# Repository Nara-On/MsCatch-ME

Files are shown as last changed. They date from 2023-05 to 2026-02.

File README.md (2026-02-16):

[][contributors-url]




<br />
<br />
<div align="center">
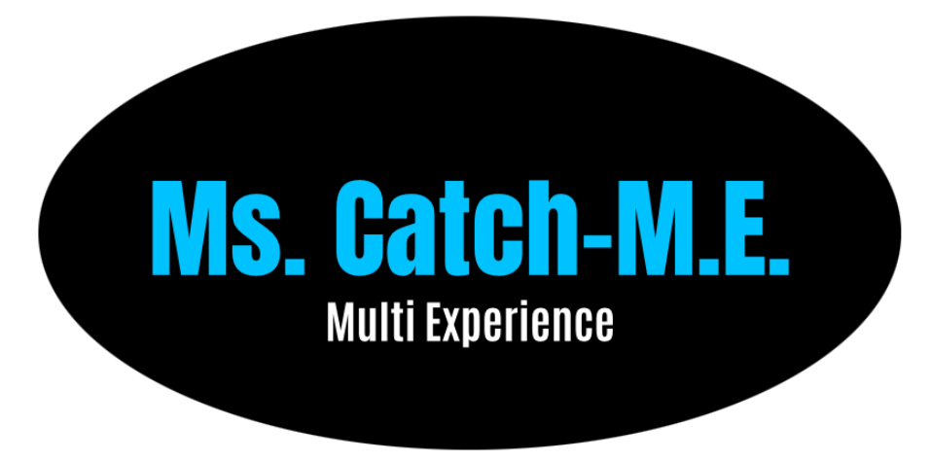
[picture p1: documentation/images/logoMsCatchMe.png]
  
  <h3 align="center">Ms. Catch-M.E.</h3>
  <p align="center">
    Arduino automated robot than plays games with you
    <br />
    https://youtu.be/ik0ufMCvqKk
    <br />
    <br />
</div>

<details>
  <summary>Table of Contents</summary>
  <br/>
    <li>
      <a href="#authors">Authors</a>
    </li>
    <li>
      <a href="#about-the-project">About The Project</a>
    </li>
    <li>
      <a href="#version-history">Version History</a>
    </li>
</details>

## Authors
Adrian Vargas Orellana - <a href="https://github.com/adriend1102">adriend1102</a> <br />
Marina Bermúdez Granados - <a href="https://github.com/nara-on">nara-on</a> <br />
Laia Rubio Castro - <a href="https://github.com/laiarubiio">laiarubiio</a> <br />
Erik Becerra Moreno - <a href="https://github.com/ERlK2021">ERlK2021</a><br />
Erik Villarreal Gallardo - <a href="https://github.com/LynxEko">LynxEko</a> 

<br >

## About the Project
<div align="center">
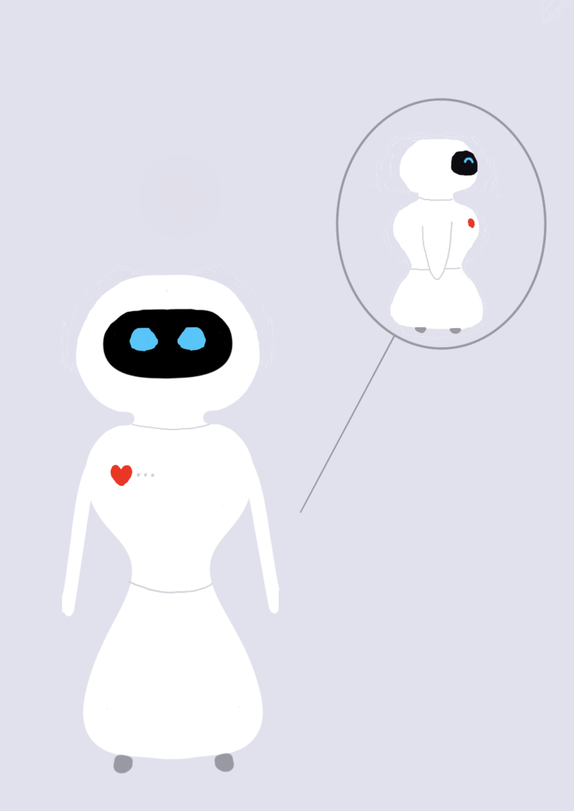
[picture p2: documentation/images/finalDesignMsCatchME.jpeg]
  
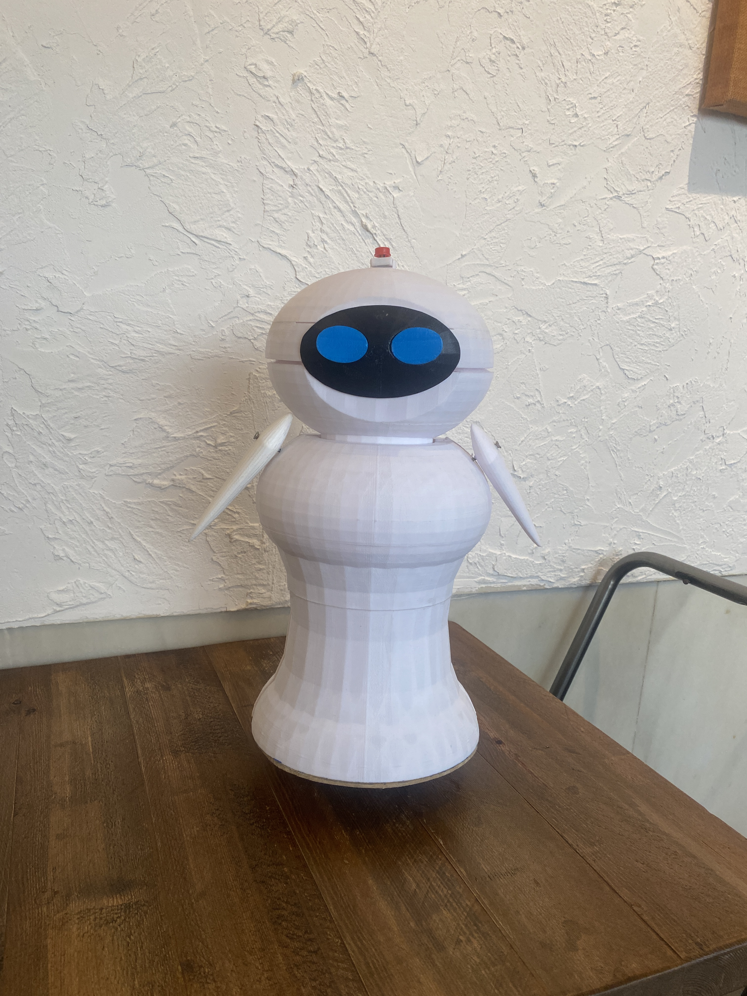
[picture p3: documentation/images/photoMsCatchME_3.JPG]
  
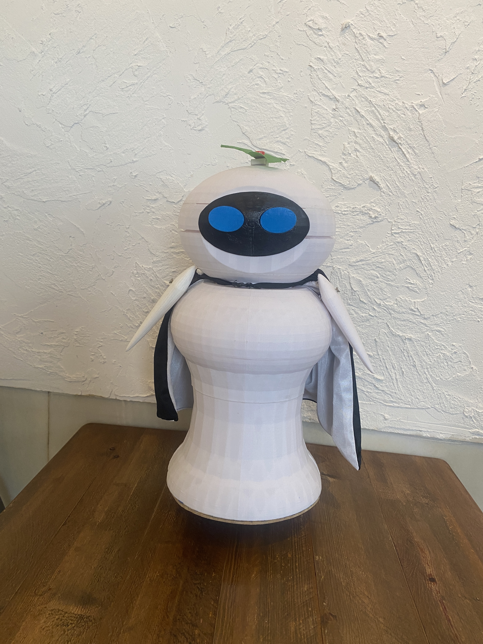
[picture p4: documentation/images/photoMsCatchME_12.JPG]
  
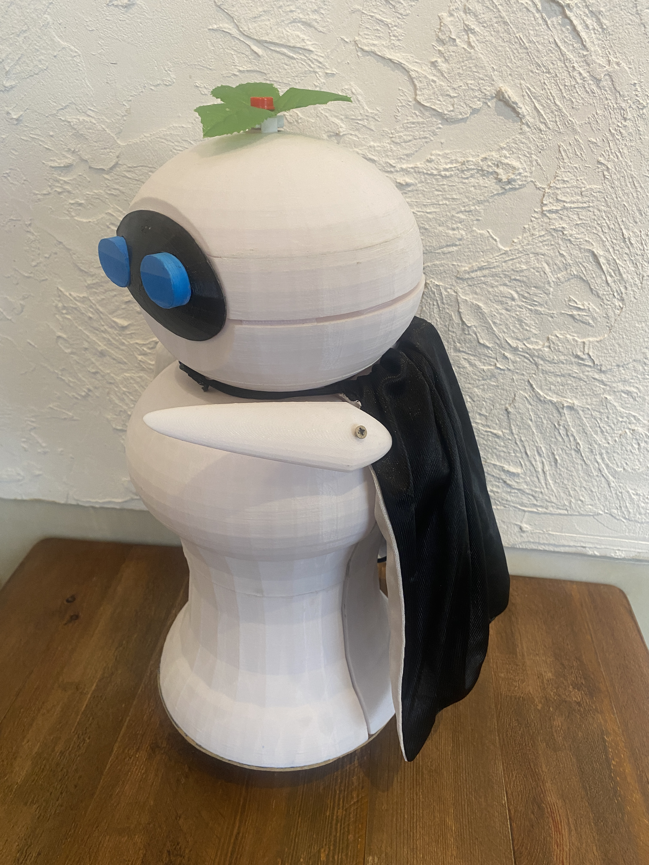
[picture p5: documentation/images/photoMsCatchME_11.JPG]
  
</div>

<br />

Ms. Catch Multi Experience (M.E.) is a Robot that can play games with children, like tag, hide and seek and red light - green light. The selection of the games will be done with a button when the robot says a specific game. In this repository stores the documentation, code and 3D models related to its development.

<br />

## Version History

* 3.0
    * <i>modulePicaPared.py</i> updated
    * <i>master.py</i> updated
    * Final report added
    * Presentation added
    * New audios added

<br />

* 2.1
    * Photos added
    * Schematics updated
* 2.0
    * <i>communication.py</i> added
    * <i>initButton.py</i> added
    * <i>catch_communication.h</i> added
    * <i>motor_control_serial.ino</i> added
    * <i>modulePicaPared.py</i> updated

<br />

* 1.1
    * <i>initAudio.py</i> added
    * <i>modulePicaPared.py</i> updated
* 1.0
    * <i>initCam.py</i> added
    * <i>moduleDeteccion.py</i> added
    * <i>modulePicaPared.py</i> added
    * <i>master.py</i> added

<br />

* 0.2
    * Software Arquitecture Diagrams added
* 0.1
    * Initial Release

[contributors-shield]: https://img.shields.io/github/contributors/othneildrew/Best-README-Template.svg?style=for-the-badge
[contributors-url]: https://github.com/Nara-On/MsCatch-ME/graphs/contributors

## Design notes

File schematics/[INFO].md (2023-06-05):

All models except the Raspberry CAM Holder and the Motor Brackets are made by ourselves.

Sources:

- Raspberry CAM Holder: https://www.thingiverse.com/thing:2987719
- Motor Brackets: https://grabcad.com/library/pololu-micro-motor-bracket-1

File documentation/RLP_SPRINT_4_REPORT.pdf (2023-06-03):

RPL - Computer Engineering. UAB (Barcelona) 2022-2023

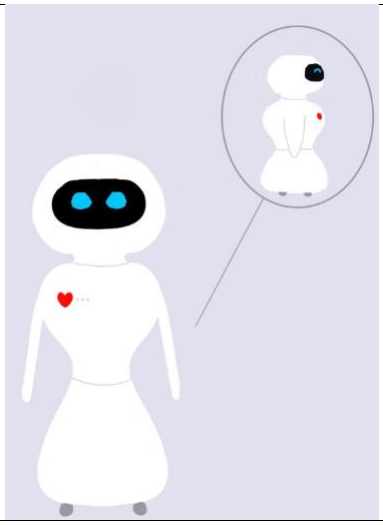
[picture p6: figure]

Ms. Catch-M.E.

Arduino automated robot than plays games with you

PROJECT SPRINT #4.
DATE: 3 Mayo 2023

Ms. Catch-M.E

Adrian Vargas Orellana

Marina Bermúdez Granados

Laia Rubio Castro

Erik Becerra Moreno

Erik Villarreal Gallardo

Ms. Catch-M.E

# Table of Contents

Strategy for validation, testing and simulation (COMPULSORY, only the strategy, you do

Sprint #2
Date: 15 April 2023
Ms. Catch-M.E | 1

Ms. Catch-M.E.

Robot que es capaç de jugar a un seguir de jocs infantils amb la finalitat d’entretenir la canalla.

Project description

Creació d’un robot que juga amb nens. Es capaç de jugar un seguir de jocs infantils amb la finalitat d’entretenir la canalla.

L’elecció del joc es farà mitjançant el boto que té. El procés consistirà en que cada vegada que el robot s’encengui enumerarà per veu cada joc, deixant un petit temps de resposta entre joc i joc. Serà en aquest temps quan el jugador haurà de prémer el boto en cas de voler aquesta modalitat. Un cop seleccionat el joc dirà: ‘Heu seleccionat x joc, voleu començar?’ En cas afirmatiu el jugador haurrà de prémer el botó i s’iniciarà el joc en els 20 segons posteriors (fent el compte enrere en els últims 10 segons per indicar-ho als jugadors). En cas negatiu, i per tant, que no es premi el botó, el robot tornarà a repetir les diferents modalitats.

Els jocs disponibles són:

‘Pilla-pilla’ :

- Funcionament: el jugador ha d’intentar esquivar el robot per a que no l’enganxi, ja que aquest l’anirà perseguint amb l’objectiu d’atrapar-lo.
- Fi: el robot contarà que ha atrapat el jugador quan detecti que la persona esta a 1 metre de distancia. En aquest moment emetrà una gravació dient: ‘Pillat’.

“Pilla-pilla invers”:

- Funcionament: el robot ha d’intentar esquivar el jugador per a que no l’enganxi, ja que aquest l’anirà perseguint amb l’objectiu d’atrapar-lo.
- Fi: el robot contarà que ha sigut atrapat quan el jugador premi el botó que te incorporat.

“Escondite”:

- Funcionament: el robot s’amaga i el jugador l’ha de trobar

Ms. Catch-M.E | 2
- Fi: quan el juagor trobi el robot haurà de polsar un botó que aquest t’he incorporat. En aquest moment el robot detectarà que ha sigut trobat i perdrà el joc.
- Com a ajuda, si el robot no ha sigut trobat en 5 min aquest emetrà un soroll per a facilitar el joc. Aquest procés es repetirà cada 5 min, si en 15 min aquest no ha sigut trobat guanyarà.

“Escondite invers”:

- Funcionament: el juagor s’amaga i el robot l’ha de trobar
- Fi: el robot anirà desplaçant-se per l’habitació i quan detecti una persona emetrà: ‘Pillat’. En cas d’haver transcorregut 15 min i no haver trobat al jugador, aquest perdrà.

“Pica-paret”:

- Funcionament: el robot es posarà de cara a la paret i emetrà una gravació de: ‘1, 2, 3 pica paret’ i es girarà per comprovar si el jugador s’ha mogut.
- Fi: quan el robot no estigui de cara a la paret, si aquest detecta que el jugador s’ha mogut emetrà una gravació dient: ‘pillat’ i aquest quedarà eliminat. El joc acabarà quan el jugador arribi a la posició del robot i premi el boto que porta incorporat o be quan el robot hagi eliminat al jugador.

Per a poder jugar a qualsevol dels jocs es necessari disposar d’un espai mes o menys ampli, amb terra pla sense imperfeccions marcades ni objectes petits sobre el sol.

Aquest robot esta pensat per a jugar amb un únic jugador per aquest motiu la dinàmica de tots els jocs seguirà la metodologia de: 1 vs 1.

Cada vegada que una partida acabi el robot emetrà una gravació que indicarà com a acabat el joc. En cas d’haver perdut emetrà música de derrota i en cas contrari música de victòria.

Segueix un disseny pensat per a infants, es a dir, d’una banda es resistent així com equilibrat per tal de poder suportar qualsevol possible col·lisió o cop per part dels jugadors. Ja que moltes vegades els nens no controlen la seva força, especialment a l’hora de jugar.

D’altra banda, es segur per als nens, no té cap cantonada o part punxant per evitar cap possible lesió durant els jocs.

Ms. Catch-M.E | 3

I finalment, en quan a la part estètica, al estar pensat per a un públic infantil, aquest segueix un disseny amigable i gens intimidant. A més, la incorporació de LEDs que reprodueixen expressions o canvis facials dependent de la situació facilita la relació nen-robot així com, fomenta la diversió. Donant un toc més humà al robot, semblant, fins a un cert punt, que s’està jugant amb una altre persona.

Electronic components

This is the list of the proposed components:

■ Adafruit Motor Shield per Arduino v2.3

■ Motor amb eix angle recte i reductora 48:1 [2]

■ Altaveu amb caixa - 3W

■ Sensor de distància per ultaso HC-SR04 [2]

■ Pulsador arcade amb interruptor (vermell)

■ Rasberry pi 3 model B+

■ AVR arduino uno rev 3

■ Bateria recarregable 8.4 V [2]

■ Arducam 5MP 1080p OV5647 RASBERRY PI

■ Adaptador 9V a jack alimentació 5.5x2.1mm positu inferior [2]

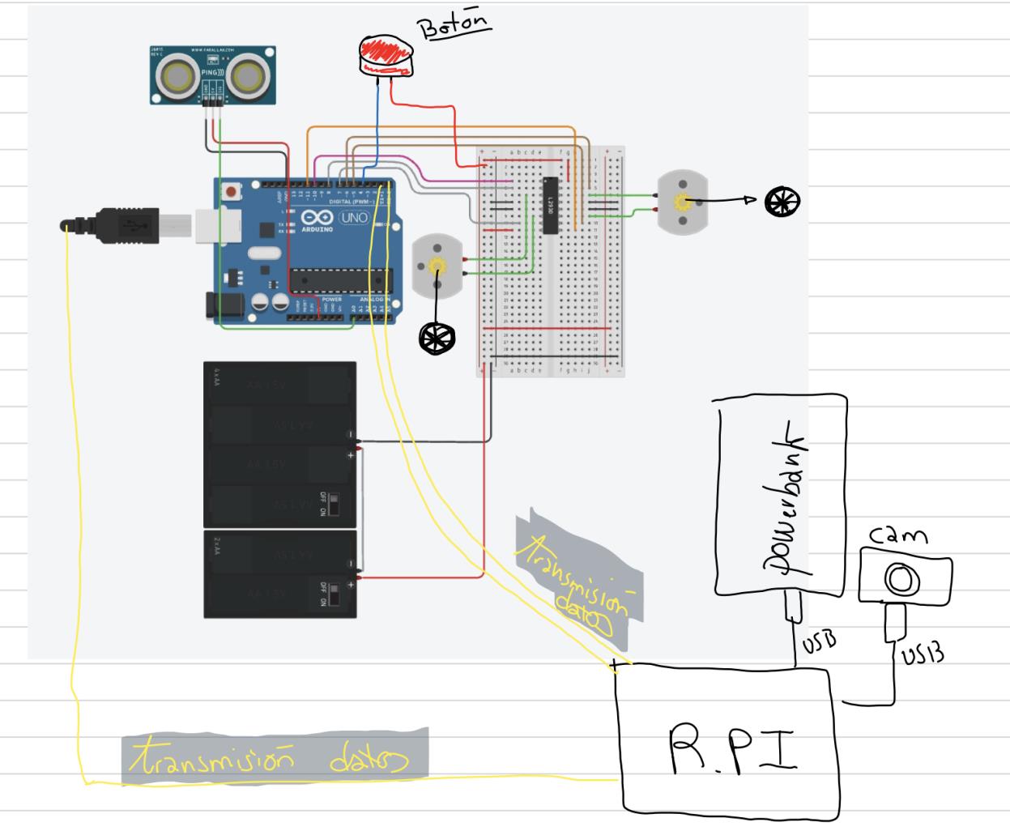
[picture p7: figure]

Ms. Catch-M.E | 4

Hardware Scheme (optional, in case that you already had this ready)

Software Architecture (COMPULSORY)

Es tractara de dos mòduls principals, el de visió controlat per una raspberry pi i el de control controlat per un arduino uno.

El mòdul d'arduino el programarem a través de C++ que anirá rebent les entrades de la raspberry i també generarà sortides cap a la raspberry. Aquestes sortides serán per exemple el sensor d'ultrasons o el botó que el nostre robot tindrá.

Ms. Catch-M.E | 5

La raspberry Pi (encara estem debatent com implementar-ho si en python o c++) però l'idea seria fer-ho conectada per wifi a una API de google. L'idea seria que enregistri el joc que volem seleccionar, quan ha començat o finalitzat el joc, també les dades de la càmera i generarà com a sortides per exemple la velocitat dels motors, a quina direcció ha de girar el robot, si hi ha moviment pel joc del pica pared...

Tot i això la arquitectura encara l'hem de aprofundir i el descrit anteriorment es una proposta provisional.

Ms. Catch-M.E | 6

Amazing contributions (COMPULSORY)

- Aquest robot podria suposar un avanç en el món de les joguines interactives, ja que moltes només tenen control de veu o tenen una funcionalitat molt simple. Entenem que tot això ha de ser pel preu, però si la nostra joguina un cop prototipada es construís en massa, els costos podrien baixar significativament.
- En el nostre robot no ho tenim pensat implementar (que es podria), però es pot extrapolar les funcionalitats del robot en un altre àmbit com per exemple el de seguretat. Per exemple, faci vigilància en una casa o un apartament i si entra algun lladre que envií una alerta a la policia.
- També s’hauria de tenir en compte que no hi ha molts robots semblants en el mercat amb tantes funcions que tinguin una intel·ligència artificial molt elevada de manera que es tracta d’un projecte complex que no s’ha comercialitzat en gran escala.

Aquest projecte està dissenyat per arribar a un 10 en el cas que es compleixi tots els objectius principals. Durant el seu desenvolupament, amb aquest robot es treballarà la part Hardware i la part Software incloent Visió per Computador. En aconseguir-ho, al final es tindrà un robot funcional capaç d’interactuar amb els participants en diversos jocs a través d’una càmara, una demo d’una joguina bastant complexa.

Extra components and 3D pieces

- Braç [1]
- Cap (base) [2]
- Cap (part superior) [3]
- Tronc inferior del cos [4]
- Tronc superior del cos [5]
- Ulls i cara [6]

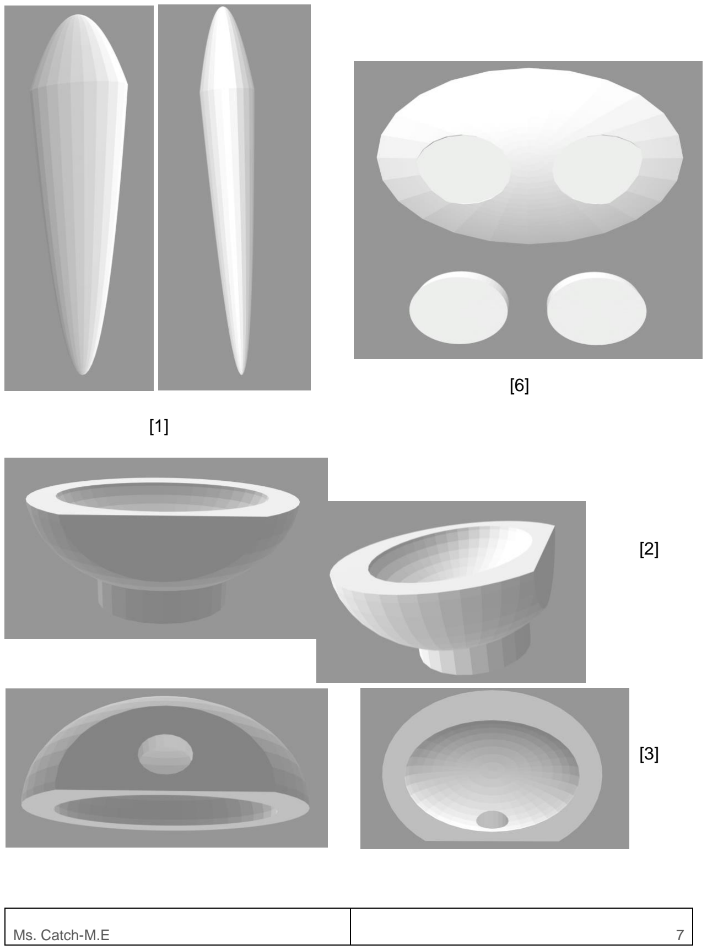
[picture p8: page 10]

Ms. Catch-M.E | 7

[6]

[1]

[2]

[3]

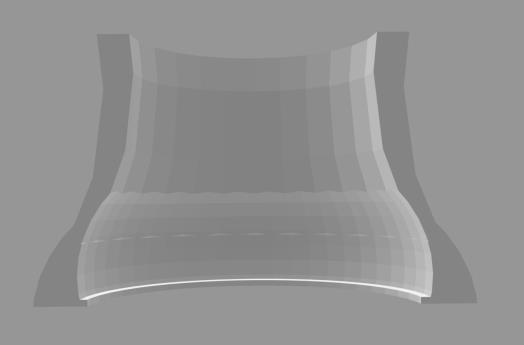
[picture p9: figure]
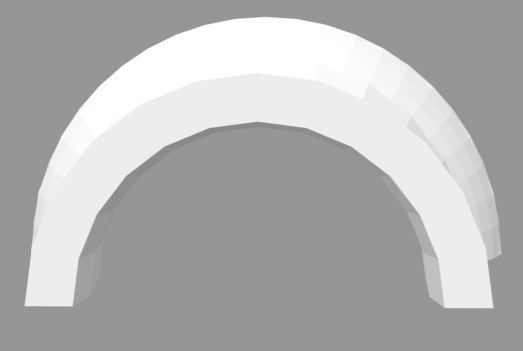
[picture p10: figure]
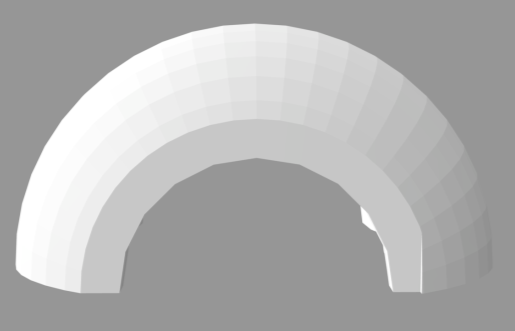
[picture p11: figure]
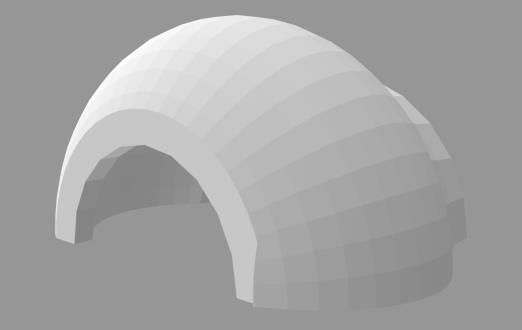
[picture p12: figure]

Ms. Catch-M.E | 8

[4]

[5]

Strategy for validation, testing and simulation (COMPULSORY, only the strategy, you do not need the tests to be done yet at this stage)

Principalment, hauríem de fer testing de cada component individualment i a més en conjunt (que accepti les entrades i generi les sortides esperades). D'aquesta manera, si hi ha alguna funció que no funciona i no trobem la raó, això ens pot ajudar.

La idea és separar totes les funcionalitats en mòduls diferents, de manera que els podem desglossar tant per fer la validació com per fer el test d'aquests.

Després anirem ajuntant els diferents mòduls i es realitzaran tests també per aquests (ex. detecció de persones i actuació del robot).

En el nostre cas intentarem seguir la metodologia de TDD (aprofitant que tenim un integrant de la menció d'ES) per tractar de fer la validació i el testing a la vegada.

Ms. Catch-M.E | 9

Foreseen risks and contingency plan

Aquestos són els riscos principals del nostre projecte. A mesura que anem fent el robot, sortiran més. Per això aquesta taula està subjecta a canvis.

Ris k # | Description | Probability (High/Medium/L ow) | Impact (High/Medium/ Low) | Contingency plan
R01 | Poca velocitat de motor | High | Medium | Intentar obtenir motors amb més potencia i/o velocitat (depen del problema) o utilitzar una serie de engranatges per adequar la força i la velocitat al nostre robot.
R02 | La recepció del wifi que rep la raspberry no és suficient | Medium | Medium | Tenir en compte alternatives de targetes de xarxa usb amb millor recepció.
R03 | Necessitat de components adicionals | Medium | High | Tractar d'extrapolar el funcionament del qual necessitem a un altre component si es pot i en cas contrari tractar d'obtenir-lo a un preu raonable.
R04 | Que una empresa diferent vulgui fer un robot similar | Low | High | Tractar d’innovar i oferir alguna cosa que aquesta empresa no pugui oferir amb el seu producte.
R05 | Que les impressions 3d no les tinguem a temps (ja sigui per la disponibilitat de les peces, que no hagin sortit bé..) | Low | High | Utilitzar una impressora 3d pròpia (Erik Becerra disposa d'una) o generar peces a partir de cartro

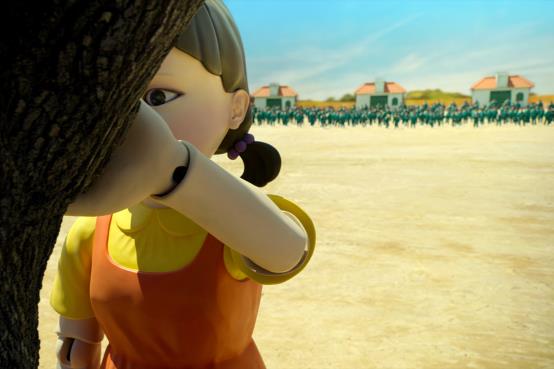
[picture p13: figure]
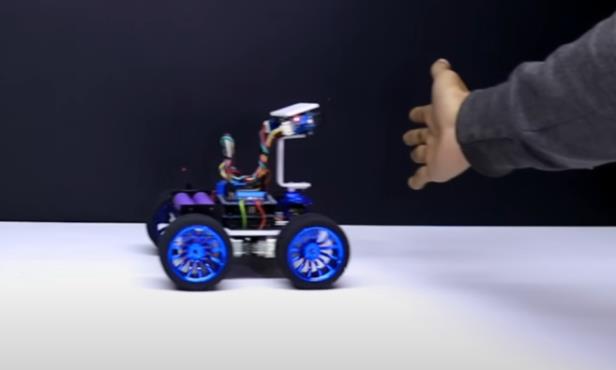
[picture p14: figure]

Ms. Catch-M.E | 10

# References

This project has been inspired by the following Internet projects:

https://www.youtube.com/watch?v=Ao7KbQLd2ms

https://www.youtube.com/watch?v=yAV5aZ0unag

https://www.thingiverse.com/thing:3703555

Statues/GLRL Game | Tag Game

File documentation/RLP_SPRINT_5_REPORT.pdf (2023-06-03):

RPL - Computer Engineering. UAB (Barcelona) 2022-2023


Ms. Catch-M.E.

Arduino automated robot than plays games with you

PROJECT SPRINT #4.
DATE: 3 Mayo 2023

Ms. Catch-M.E

Adrian Vargas Orellana

Marina Bermúdez Granados

Laia Rubio Castro

Erik Becerra Moreno

Erik Villarreal Gallardo

Ms. Catch-M.E

# Table of Contents

Project description | 1
Electronic components | 3
Hardware Scheme (optional, in case that you already had this ready) | 3
Software Architecture (COMPULSORY) | 4
Amazing contributions (COMPULSORY) | 5
Extra components and 3D pieces | 5
[4] 7
Strategy for validation, testing and simulation (COMPULSORY, only the strategy, you do
not need the tests to be done yet at this stage) | 7
Foreseen risks and contingency plan | 8

Sprint #5
Date: 5 june 2023
Ms. Catch-M.E | 1

Ms. Catch-M.E.

Robot que es capaç de jugar a un seguir de jocs infantils amb la finalitat d’entretenir la canalla.

Project description

Creació d’un robot que juga amb nens. Es capaç de jugar un seguir de jocs infantils amb la finalitat d’entretenir la canalla.

L’elecció del joc es farà mitjançant el boto que té. El procés consistirà en que cada vegada que el robot s’encengui enumerarà per veu cada joc, deixant un petit temps de resposta entre joc i joc. Serà en aquest temps quan el jugador haurà de prémer el boto en cas de voler aquesta modalitat. Un cop seleccionat el joc dirà: ‘Heu seleccionat x joc, voleu començar?’ En cas afirmatiu el jugador haurrà de prémer el botó i s’iniciarà el joc en els 20 segons posteriors (fent el compte enrere en els últims 10 segons per indicar-ho als jugadors). En cas negatiu, i per tant, que no es premi el botó, el robot tornarà a repetir les diferents modalitats.

Els jocs disponibles són:

‘Pilla-pilla’ :

- Funcionament: el jugador ha d’intentar esquivar el robot per a que no l’enganxi, ja que aquest l’anirà perseguint amb l’objectiu d’atrapar-lo.
- Fi: el robot contarà que ha atrapat el jugador quan detecti que la persona esta a 1 metre de distancia. En aquest moment emetrà una gravació dient: ‘Pillat’.

“Pilla-pilla invers”:

- Funcionament: el robot ha d’intentar esquivar el jugador per a que no l’enganxi, ja que aquest l’anirà perseguint amb l’objectiu d’atrapar-lo.
- Fi: el robot contarà que ha sigut atrapat quan el jugador premi el botó que te incorporat.

“Escondite”:

- Funcionament: el robot s’amaga i el jugador l’ha de trobar

Ms. Catch-M.E | 2
- Fi: quan el juagor trobi el robot haurà de polsar un botó que aquest t’he incorporat. En aquest moment el robot detectarà que ha sigut trobat i perdrà el joc.
- Com a ajuda, si el robot no ha sigut trobat en 5 min aquest emetrà un soroll per a facilitar el joc. Aquest procés es repetirà cada 5 min, si en 15 min aquest no ha sigut trobat guanyarà.

“Escondite invers”:

- Funcionament: el juagor s’amaga i el robot l’ha de trobar
- Fi: el robot anirà desplaçant-se per l’habitació i quan detecti una persona emetrà: ‘Pillat’. En cas d’haver transcorregut 15 min i no haver trobat al jugador, aquest perdrà.

“Pica-paret”:

- Funcionament: el robot es posarà de cara a la paret i emetrà una gravació de: ‘1, 2, 3 pica paret’ i es girarà per comprovar si el jugador s’ha mogut.
- Fi: quan el robot no estigui de cara a la paret, si aquest detecta que el jugador s’ha mogut emetrà una gravació dient: ‘pillat’ i aquest quedarà eliminat. El joc acabarà quan el jugador arribi a la posició del robot i premi el boto que porta incorporat o be quan el robot hagi eliminat al jugador.

Per a poder jugar a qualsevol dels jocs es necessari disposar d’un espai mes o menys ampli, amb terra pla sense imperfeccions marcades ni objectes petits sobre el sol.

Aquest robot esta pensat per a jugar amb un únic jugador per aquest motiu la dinàmica de tots els jocs seguirà la metodologia de: 1 vs 1.

Cada vegada que una partida acabi el robot emetrà una gravació que indicarà com a acabat el joc. En cas d’haver perdut emetrà música de derrota i en cas contrari música de victòria.

Segueix un disseny pensat per a infants, es a dir, d’una banda es resistent així com equilibrat per tal de poder suportar qualsevol possible col·lisió o cop per part dels jugadors. Ja que moltes vegades els nens no controlen la seva força, especialment a l’hora de jugar.

D’altra banda, es segur per als nens, no té cap cantonada o part punxant per evitar cap possible lesió durant els jocs.

Ms. Catch-M.E | 3

I finalment, en quan a la part estètica, al estar pensat per a un públic infantil, aquest segueix un disseny amigable i gens intimidant. A més, la incorporació de LEDs que reprodueixen expressions o canvis facials dependent de la situació facilita la relació nen-robot així com, fomenta la diversió. Donant un toc més humà al robot, semblant, fins a un cert punt, que s’està jugant amb una altre persona.

Electronic components

This is the list of the proposed components:

■ Adafruit Motor Shield per Arduino v2.3

■ Motor amb eix angle recte i reductora 48:1 [2]

■ Altaveu amb caixa - 3W

■ Sensor de distància per ultaso HC-SR04 [2]

■ Pulsador arcade amb interruptor (vermell)

■ Rasberry pi 3 model B+

■ AVR arduino uno rev 3

■ Bateria recarregable 8.4 V [2]

■ Arducam 5MP 1080p OV5647 RASBERRY PI

■ Adaptador 9V a jack alimentació 5.5x2.1mm positu inferior [2]


Ms. Catch-M.E | 4

Hardware Scheme (optional, in case that you already had this ready)

Software Architecture (COMPULSORY)

Es tractara de dos mòduls principals, el de visió controlat per una raspberry pi i el de control controlat per un arduino uno.

El mòdul d'arduino el programarem a través de C++ que anirá rebent les entrades de la raspberry i també generarà sortides cap a la raspberry. Aquestes sortides serán per exemple el sensor d'ultrasons o el botó que el nostre robot tindrá.

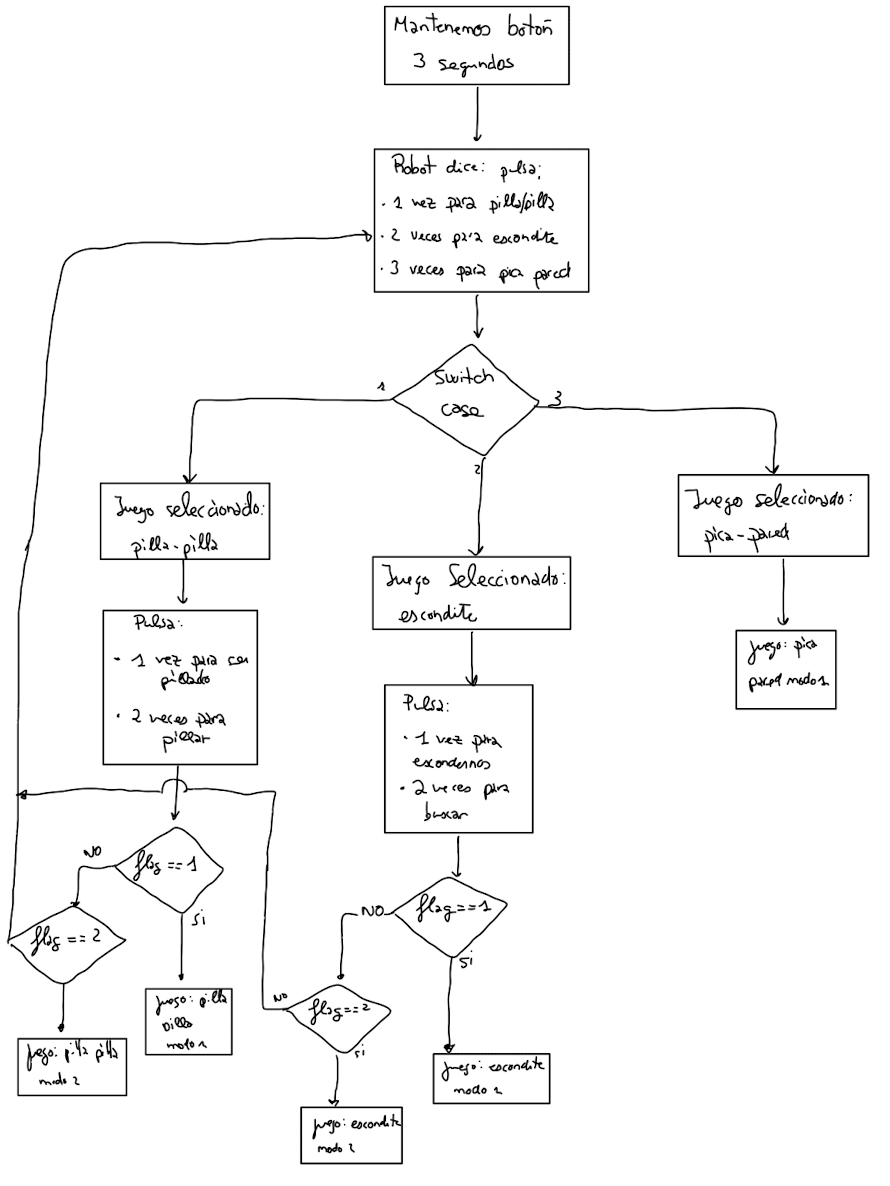
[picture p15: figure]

Ms. Catch-M.E | 5

La raspberry Pi (encara estem debatent com implementar-ho si en python o c++) però l'idea seria fer-ho conectada per wifi a una API de google. L'idea seria que enregistri el joc que volem seleccionar, quan ha començat o finalitzat el joc, també les dades de la càmera i generarà com a sortides per exemple la velocitat dels motors, a quina direcció ha de girar el robot, si hi ha moviment pel joc del pica pared...

Tot i això la arquitectura encara l'hem de aprofundir i el descrit anteriorment es una proposta provisional.

### Diagrames de fluxe

Selecció de fluxe

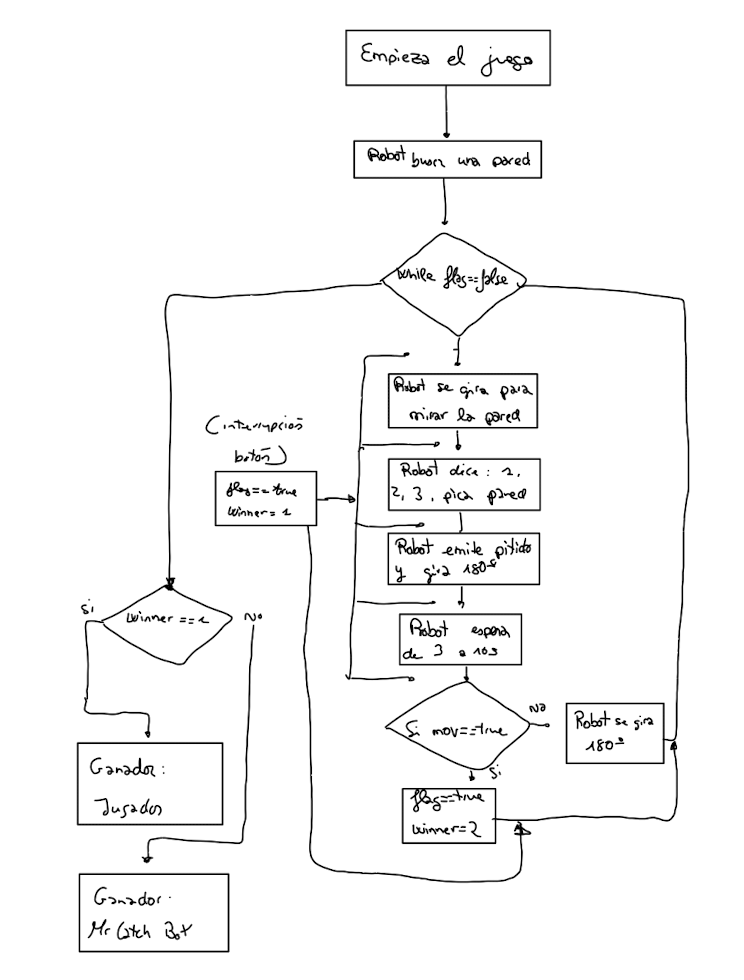
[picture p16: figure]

Ms. Catch-M.E | 6

Pica-paret

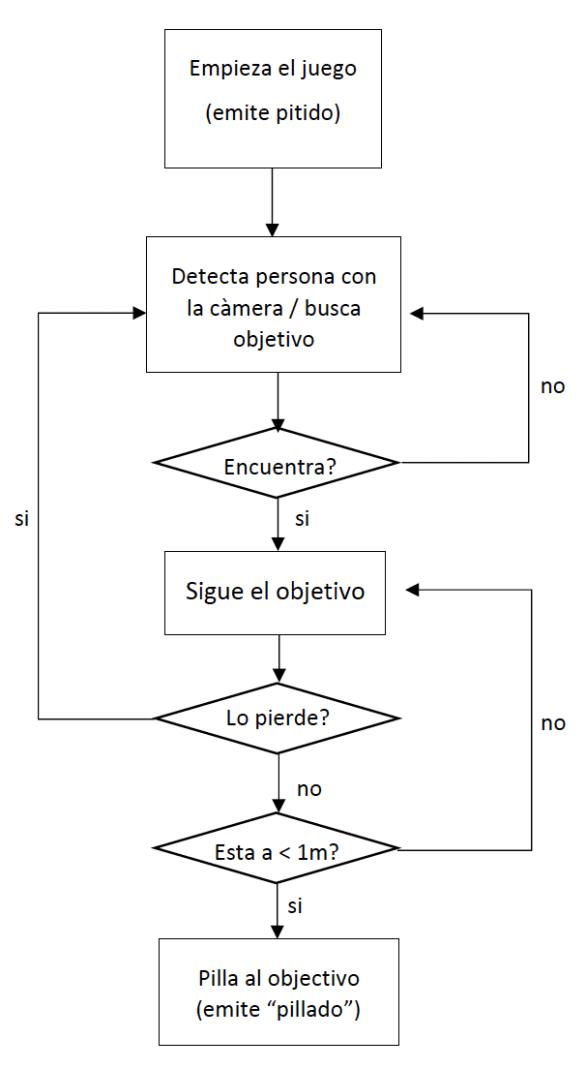
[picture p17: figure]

Ms. Catch-M.E | 7

Pilla-pilla:

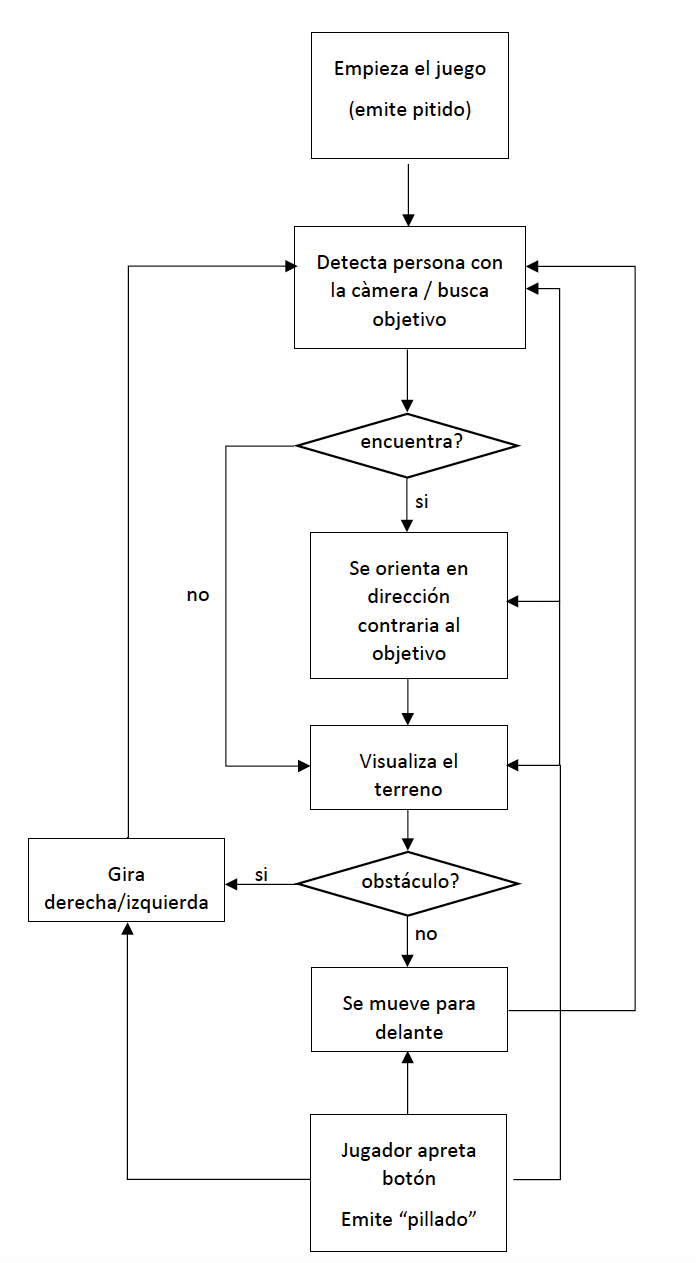
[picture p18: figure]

Ms. Catch-M.E | 8

Pilla-pilla invers:

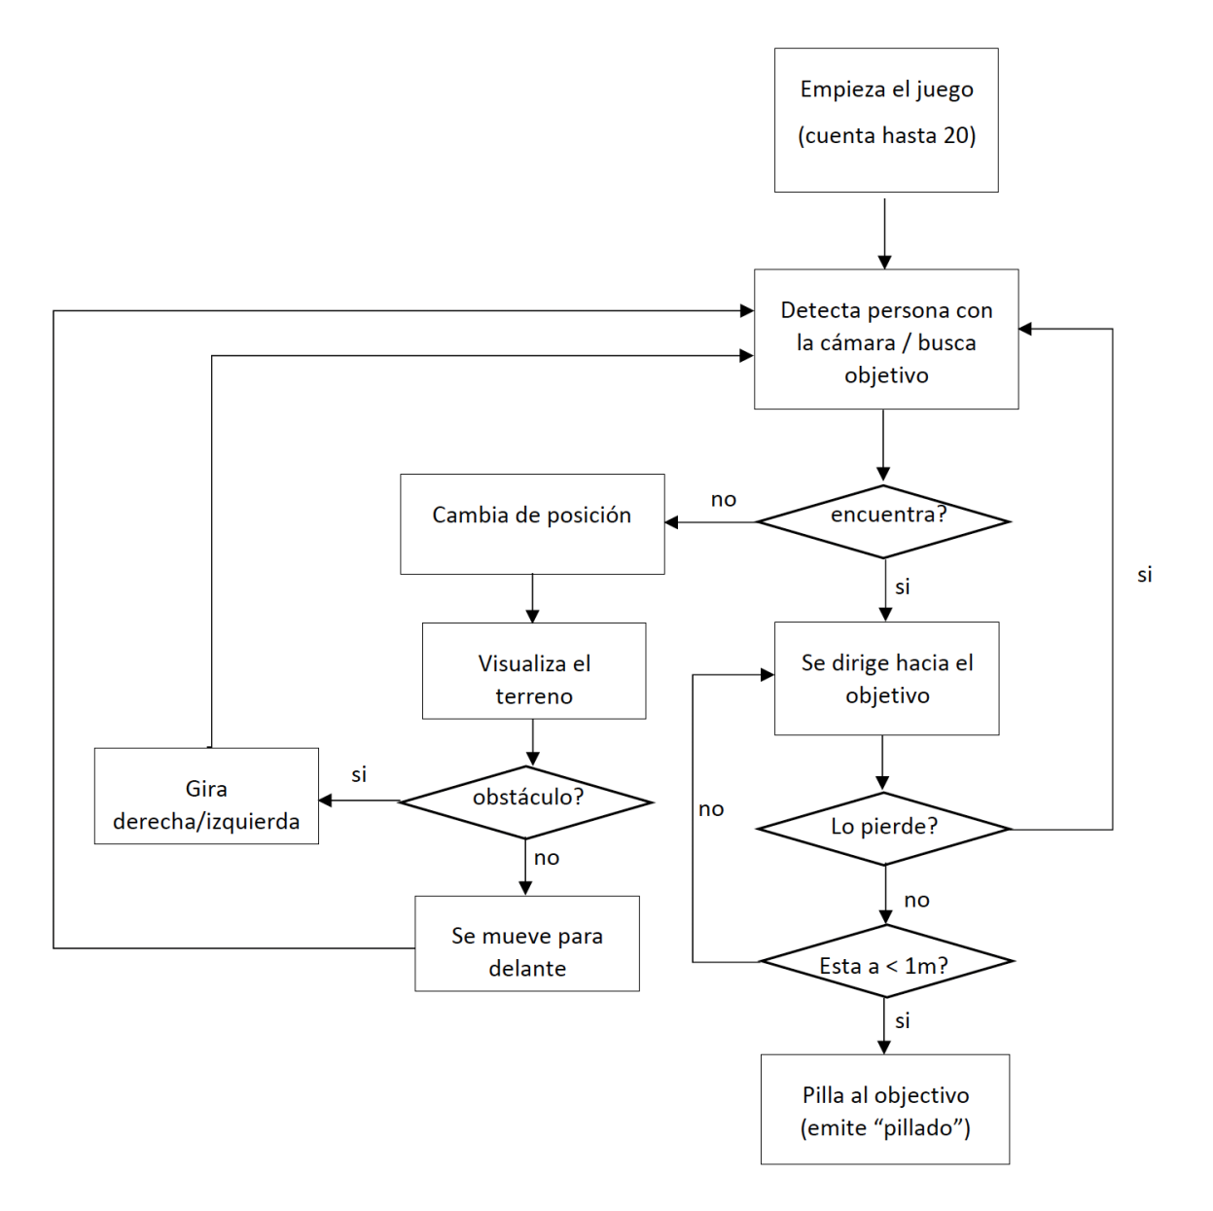
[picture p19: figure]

Ms. Catch-M.E | 9

Escondite:

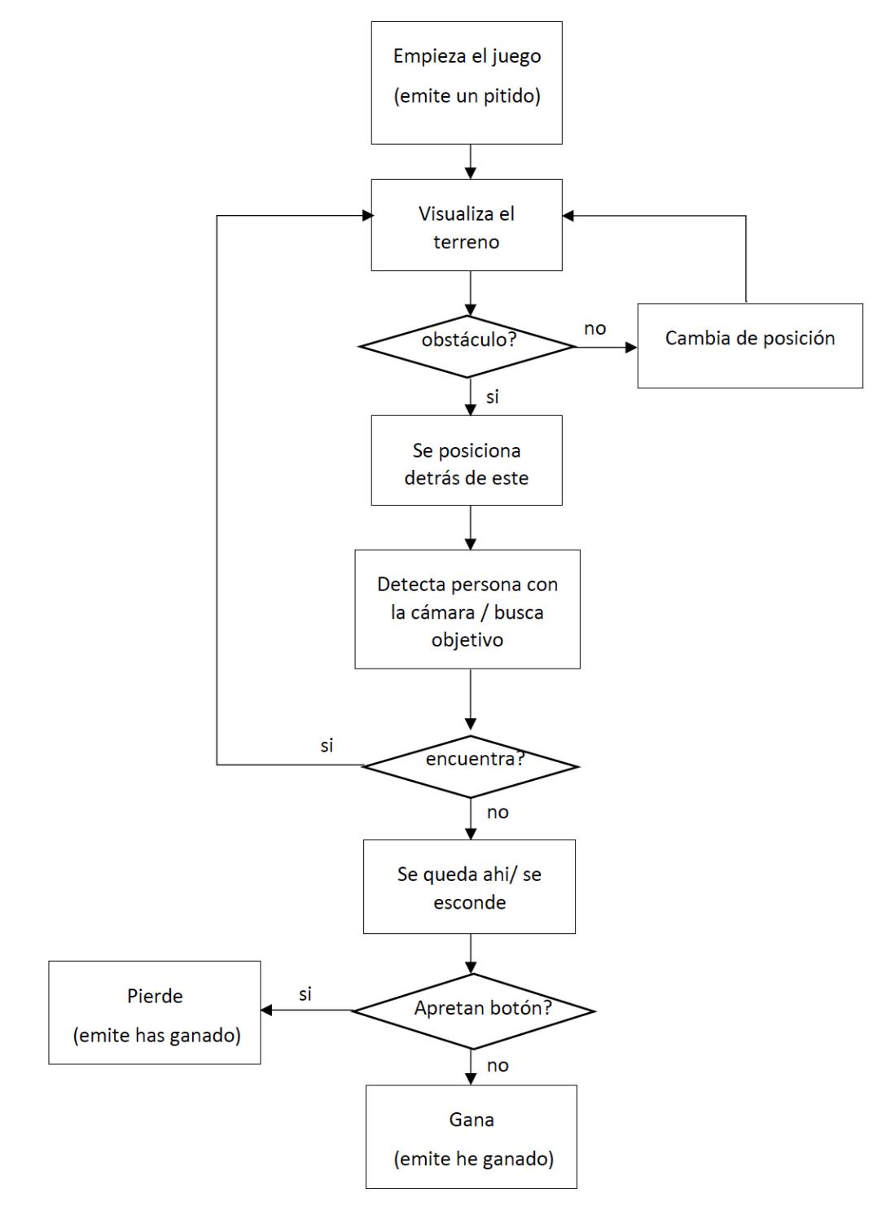
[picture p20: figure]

Ms. Catch-M.E | 10

Escondite invers:

Ms. Catch-M.E | 11

Amazing contributions (COMPULSORY)

- Aquest robot podria suposar un avanç en el món de les joguines interactives, ja que moltes només tenen control de veu o tenen una funcionalitat molt simple. Entenem que tot això ha de ser pel preu, però si la nostra joguina un cop prototipada es construís en massa, els costos podrien baixar significativament.
- En el nostre robot no ho tenim pensat implementar (que es podria), però es pot extrapolar les funcionalitats del robot en un altre àmbit com per exemple el de seguretat. Per exemple, faci vigilància en una casa o un apartament i si entra algun lladre que envií una alerta a la policia.
- També s’hauria de tenir en compte que no hi ha molts robots semblants en el mercat amb tantes funcions que tinguin una intel·ligència artificial molt elevada de manera que es tracta d’un projecte complex que no s’ha comercialitzat en gran escala.

Aquest projecte està dissenyat per arribar a un 10 en el cas que es compleixi tots els objectius principals. Durant el seu desenvolupament, amb aquest robot es treballarà la part Hardware i la part Software incloent Visió per Computador. En aconseguir-ho, al final es tindrà un robot funcional capaç d’interactuar amb els participants en diversos jocs a través d’una càmara, una demo d’una joguina bastant complexa.

Extra components and 3D pieces

- Braç [1]
- Cap (base) [2]
- Cap (part superior) [3]
- Tronc inferior del cos [4]
- Tronc superior del cos [5]
- Ulls i cara [6]

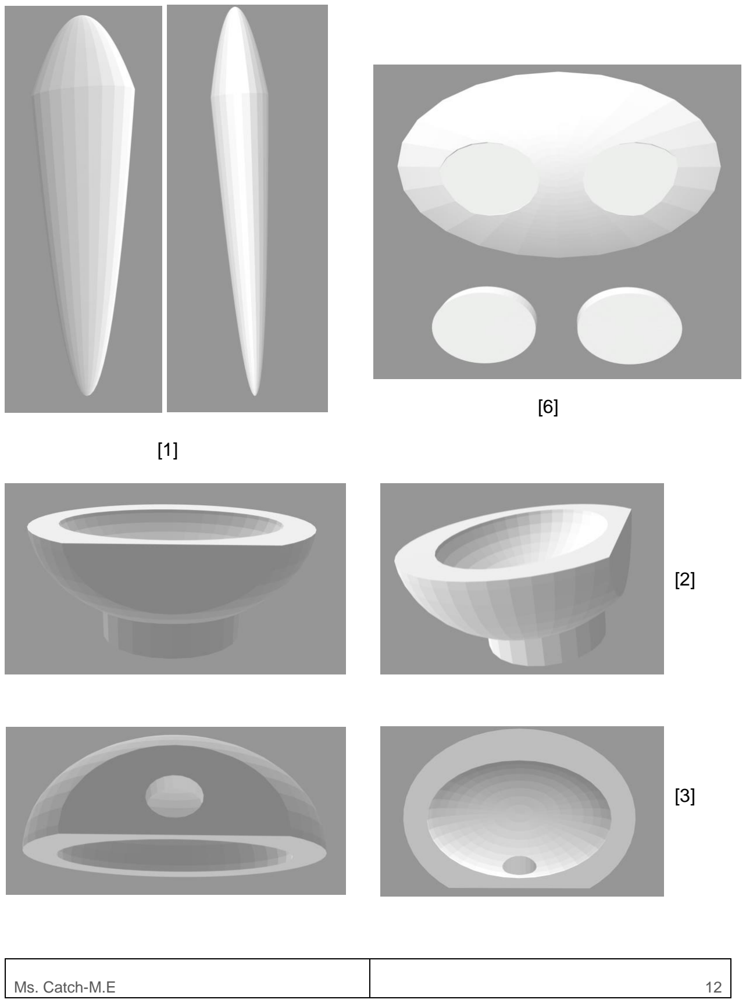
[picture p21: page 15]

Ms. Catch-M.E | 12

[6]

[1]

[2]

[3]


Ms. Catch-M.E | 13

[4]

[5]

Strategy for validation, testing and simulation (COMPULSORY, only the strategy, you do not need the tests to be done yet at this stage)

Principalment, hauríem de fer testing de cada component individualment i a més en conjunt (que accepti les entrades i generi les sortides esperades). D'aquesta manera, si hi ha alguna funció que no funciona i no trobem la raó, això ens pot ajudar.

La idea és separar totes les funcionalitats en mòduls diferents, de manera que els podem desglossar tant per fer la validació com per fer el test d'aquests.

Després anirem ajuntant els diferents mòduls i es realitzaran tests també per aquests (ex. detecció de persones i actuació del robot).

En el nostre cas intentarem seguir la metodologia de TDD (aprofitant que tenim un integrant de la menció d'ES) per tractar de fer la validació i el testing a la vegada.

Ms. Catch-M.E | 14

Foreseen risks and contingency plan

Aquestos són els riscos principals del nostre projecte. A mesura que anem fent el robot, sortiran més. Per això aquesta taula està subjecta a canvis.

Ris k # | Description | Probability (High/Medium/L ow) | Impact (High/Medium/ Low) | Contingency plan
R01 | Poca velocitat de motor | High | Medium | Intentar obtenir motors amb més potencia i/o velocitat (depen del problema) o utilitzar una serie de engranatges per adequar la força i la velocitat al nostre robot.
R02 | La recepció del wifi que rep la raspberry no és suficient | Medium | Medium | Tenir en compte alternatives de targetes de xarxa usb amb millor recepció.
R03 | Necessitat de components adicionals | Medium | High | Tractar d'extrapolar el funcionament del qual necessitem a un altre component si es pot i en cas contrari tractar d'obtenir-lo a un preu raonable.
R04 | Que una empresa diferent vulgui fer un robot similar | Low | High | Tractar d’innovar i oferir alguna cosa que aquesta empresa no pugui oferir amb el seu producte.
R05 | Que les impressions 3d no les tinguem a temps (ja sigui per la disponibilitat de les peces, que no hagin sortit bé..) | Low | High | Utilitzar una impressora 3d pròpia (Erik Becerra disposa d'una) o generar peces a partir de cartro


Ms. Catch-M.E | 15

# References

This project has been inspired by the following Internet projects:

https://www.youtube.com/watch?v=Ao7KbQLd2ms

https://www.youtube.com/watch?v=yAV5aZ0unag

https://www.thingiverse.com/thing:3703555

Statues/GLRL Game | Tag Game

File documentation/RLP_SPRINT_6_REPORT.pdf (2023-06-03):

RPL - Computer Engineering. UAB (Barcelona) 2022-2023

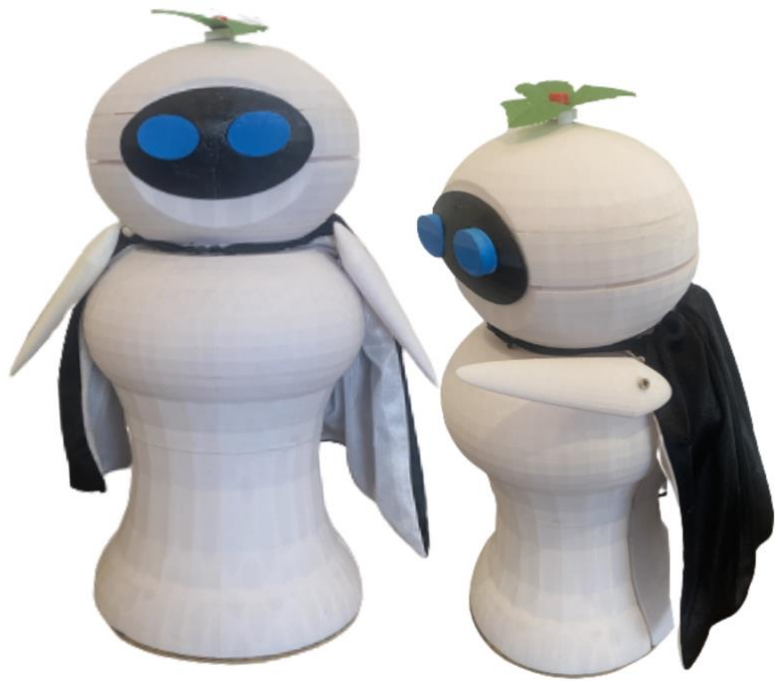
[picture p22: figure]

Ms. Catch-M.E.

Arduino automated robot that plays games with you

PROJECT SPRINT #6
DATE: 5 Juny 2023

Adrian Vargas Orellana
Marina Bermúdez Granados
Laia Rubio Castro
Erik Becerra Moreno
Erik Villarreal Gallardo

Ms. Catch-M.E

# Índex

Descripció de Projecte | 1
Components Electrònics | 4
Esquema Hardware | 5
Arquitectura del Software | 6
Diagrames de l’arquitectura del Software | 7
Mòdul Selecció de joc | 7
Mòdul PicaPared | 8
Mòduls Escondite | 8
Mòduls PillaPilla | 8
Diagrames de flux | 9
Selecció de Joc | 9
PicaPared | 10
PillaPilla1 | 11
PillaPilla2 | 11
Escondite1 | 12
Escondite2 | 13
Contribucions Rellevants | 14
Components Extra i Peces 3D | 15
Estrategia de Validació, Testing i Simulació | 16
Riscos Detectats i Plans de Contingencia | 17
Referències | 19

Sprint #6
Date: 5 Juny 2023
Ms. Catch-M.E | 1

Ms. Catch-M.E.

Robot capaç de jugar a un seguit de jocs infantils amb la finalitat d’entretenir la canalla.

Descripció de Projecte

El projecte es basarà en la creació d’un robot capaç de jugar un seguit de jocs infantils amb la finalitat d’entretenir la canalla. L’elecció del joc es farà mitjançant un botó: Cada vegada que el robot s’encengui s’enumeraran per àudio cada joc, deixant un petit temps de resposta entre joc i joc. Serà en aquest temps quan el jugador haurà de prémer el botó en cas de voler aquesta modalitat. En cas negatiu, és a dir, que no es premi el botó, el robot tornarà a repetir les diferents modalitats. Entre totes les opcions, s’ha decidit adaptar 5 jocs diferents:

Pilla-pilla

El jugador ha d’intentar esquivar el robot perquè no l’enganxi, ja que aquest l’anirà perseguint. El robot comptarà que ha atrapat el jugador quan detecti que aquesta persona està a menys d’un metre de distància. En aquest moment, emetrà una gravació indicant que el robot l’ha pillat, donant fi al joc.

Pilla-pilla invers

Invertint el funcionament del Pilla-Pilla ja explicat, el robot ha d’intentar esquivar el jugador perquè no l’enganxi. El robot contarà que ha sigut atrapat quan el jugador premi el botó que tindrà incorporat.

Escondite

El robot s’amagarà i el jugador l’haurà de trobar. Quan es trobi el robot, s’haurà de prémer el botó que tindrà incorporat. En aquest moment, el robot detectarà que ha sigut trobat i haurà

Ms. Catch-M.E | 2

guanyat el jugador. En cas que el robot no hagi sigut trobat en 5 minuts, aquest emetrà un soroll per ajudar al jugador. Aquest procés es repetirà cada 5 minuts fins a arribar als 15 minuts, on es considerarà que no s’ha pogut trobar i el robot es considerarà el guanyador.

Escondite invers

Invertint el funcionament del joc anterior, el jugador serà qui s’amaga i el robot l’haurà de trobar. Aquest s’anirà desplaçant per l’habitació fins que detecti una persona, per emetre un àudio indicant que ha trobat a una persona i que ha guanyat el joc. En canvi, si han transcorregut 15 minuts i no s’ha trobat al jugador, aquest serà el guanyador.

Pica Pared

El robot es posarà de cara a la paret i emetrà una gravació abans de girar-se per comprovar si el jugador s’ha mogut. Si aquest detecta moviment, emetrà una gravació dient que el jugador ha quedat eliminat. El joc acabarà quan el jugador arribi a la posició del robot i premi el botó que porta incorporat o bé quan el robot hagi eliminat al jugador.

Per poder jugar a qualsevol dels jocs és necessari disposar d’un espai més o menys ampli, amb terra pla sense imperfeccions marcades ni objectes petits sobre el sol. Aquest robot està dissenyat per jugar amb un únic jugador, la dinàmica de tots els jocs seguirà la metodologia de jugador contra el robot. Cada vegada que una partida acabi, el robot emetrà una gravació que indicarà com a acabat el joc: En cas d’haver perdut emetrà música de derrota i en cas contrari música de victòria.

Com, al cap i a la fi, el robot té com a objectiu entretenir a nens petits, el seu disseny haurà de tenir unes qualitats especials pensades pel seu funcionament en aquests entorns. D’una banda, haurà de ser resistent així com equilibrat per tal de poder suportar qualsevol possible col·lisió o cop per part dels jugadors, ja que els nens petits han d’aprendre a controlar la seva força. D’altra banda, ha de tenir un disseny segur per als nens, sense cap cantonada o part punxant per evitar cap possible lesió durant els jocs. Finalment, la part estètica ha d’estar plantejada per a un públic infantil. El robot seguirà un disseny amigable i gens intimidant. A més a més, amb un disseny base senzill es podrien fer decoracions per personalitzar cada joguina, com una capa de superheroi o un vestit de princesa.

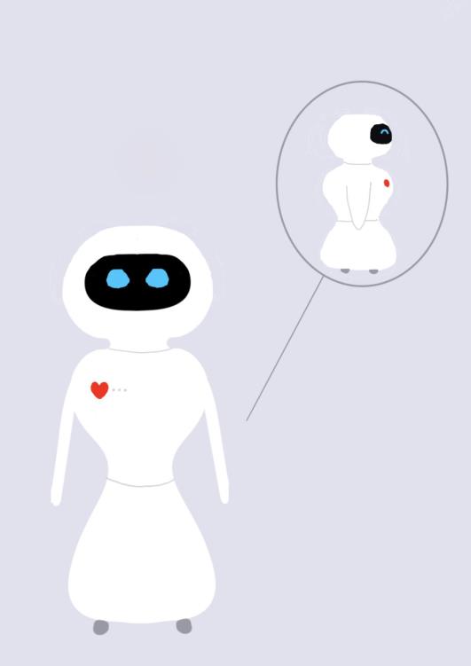
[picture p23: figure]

Ms. Catch-M.E | 3

Disseny del robot

Ms. Catch-M.E | 4

Components Electrònics

A continuació, hi ha una llista de tots els components proposats per al desenvolupament del projecte:

➔ Adafruit Motor Shield per Arduino v2.3

➔ Motor amb eix angle recte i reductora 150:1 [2]

➔ Altaveu amb caixa - 3W

➔ Sensor de distància per ultasò HC-SR04 [2]

➔ Polsador arcade amb interruptor (vermell)

➔ Rasberry Pi 3 model B+

➔ AVR arduino uno rev 3

➔ Portapilas 6V

➔ Powerbank

➔ Arducam 5MP 1080p OV5647 RASBERRY PI

➔ Adaptador 9V a jack alimentació 5.5x2.1mm positiu inferior [1]

Aquesta és la llista teòrica dels materials necessaris per al desenvolupament del projecte. Tot i això, a la seva implementació han sorgit diversos problemes que han obligat el grup a fer alguns canvis. El més greu va ser la substitució de la Rasberry Pi 3 model B+ per una Raspberry Pi 2. Durant les primeres proves que es van fer amb la connexió de la primera Raspberry amb els altres elements, com la càmera i l’altaveu, es va formar un curtcircuit que va cremar-la. Afortunadament, un dels membres del grup va poder aconseguir la segona Raspberry. Per la mateixa raó, també es va d’haver de substituir l’altaveu.

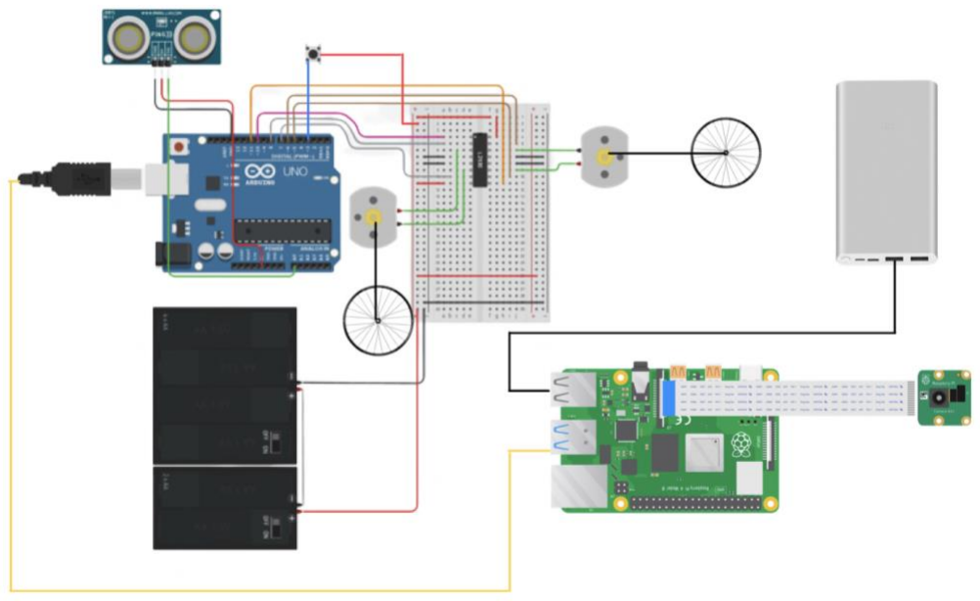
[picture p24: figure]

Ms. Catch-M.E | 5

Esquema Hardware

A continuació es mostra les connexions de tots els components electrònics pel funcionament del robot.

Ms. Catch-M.E | 6

Arquitectura del Software

L’arquitectura del software consistirà en dos mòduls principals: El de visió per computador controlat per una Raspberry Pi i el de control dels components electrònics per un Arduino Uno.

La placa d'Arduino, la qual estarà programada en C++, anirà rebent les entrades de la Raspberry Pi i retornant les sortides corresponents. Aquestes sortides indicaran els estats dels components elèctrics, com per exemple que detecta el sensor d'ultrasons o si un botó està premut o no. La Raspberry Pi estarà programada en Python, per poder fer servir llibreries com OpenCv per la part de visió per computador. Durant el seu funcionament, la Raspberry serà la responsable de moltes tasques essencials, entre elles: Enregistrar el joc que es vol seleccionar, executar la lògica interna de cada joc i utilitzar les dades de la càmera. Amb la informació de la càmera, s’han de generar sortides com la velocitat dels motors, a quina direcció ha de girar el robot, o si s’ha detectat moviment o persones pels jocs del Pica Pared o Escondite.

Per tal d’organitzar la implementació de tots aquests aspectes, s’han fet esquemes dels mòduls necessaris des de l’inici del funcionament del robot fins al final de cada joc. El mòdul principal serà el responsable de la selecció dels jocs, el qual connectarà als altres mòduls, un per cada joc. Algunes funcionalitats lògiques dels jocs són compartides o molt semblants entre elles, per tant, també es poden separar en diferents mòduls independents. En total, hi ha 6 mòduls independents diferents: El mòdul de detecció de moviment i el de detecció de persones, el mòdul de Search per buscar els jugadors, el mòdul de Follow per seguir als jugadors, el mòdul Escape per poder escapar i el mòdul Hide per trobar un amagatall.

A més a més dels esquemes amb l’arquitectura del software, també s’ha considerat rellevant fer els diagrames de flux de cada joc per poder concretar que seguit d’accions haurà de fer el robot.

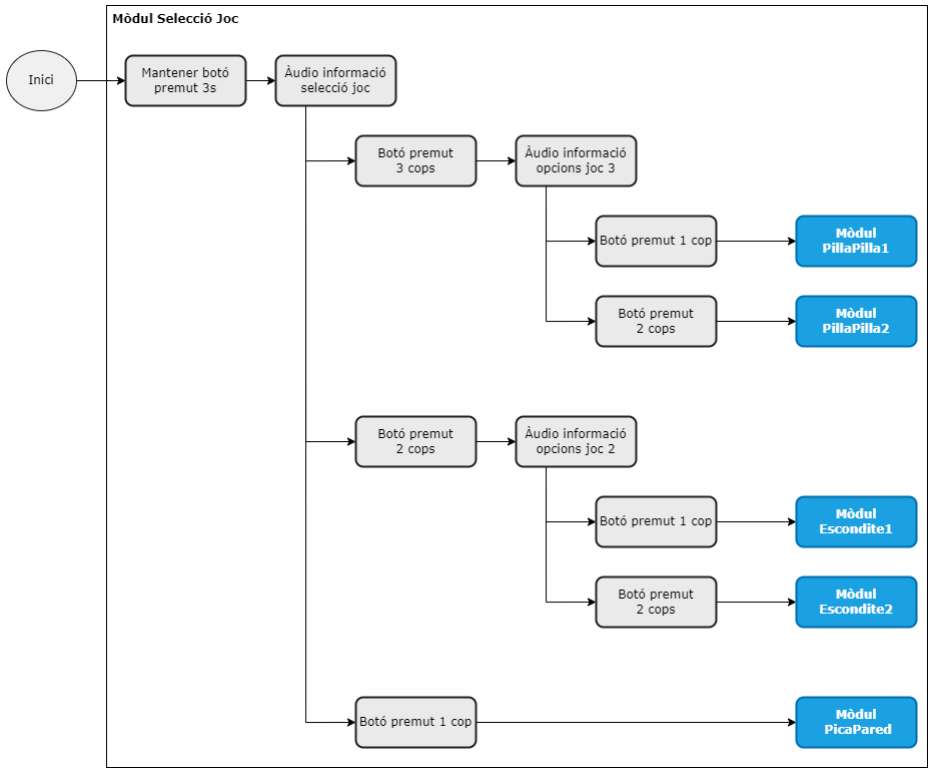
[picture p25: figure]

Ms. Catch-M.E | 7

Diagrames de l’arquitectura del Software

Mòdul Selecció de joc

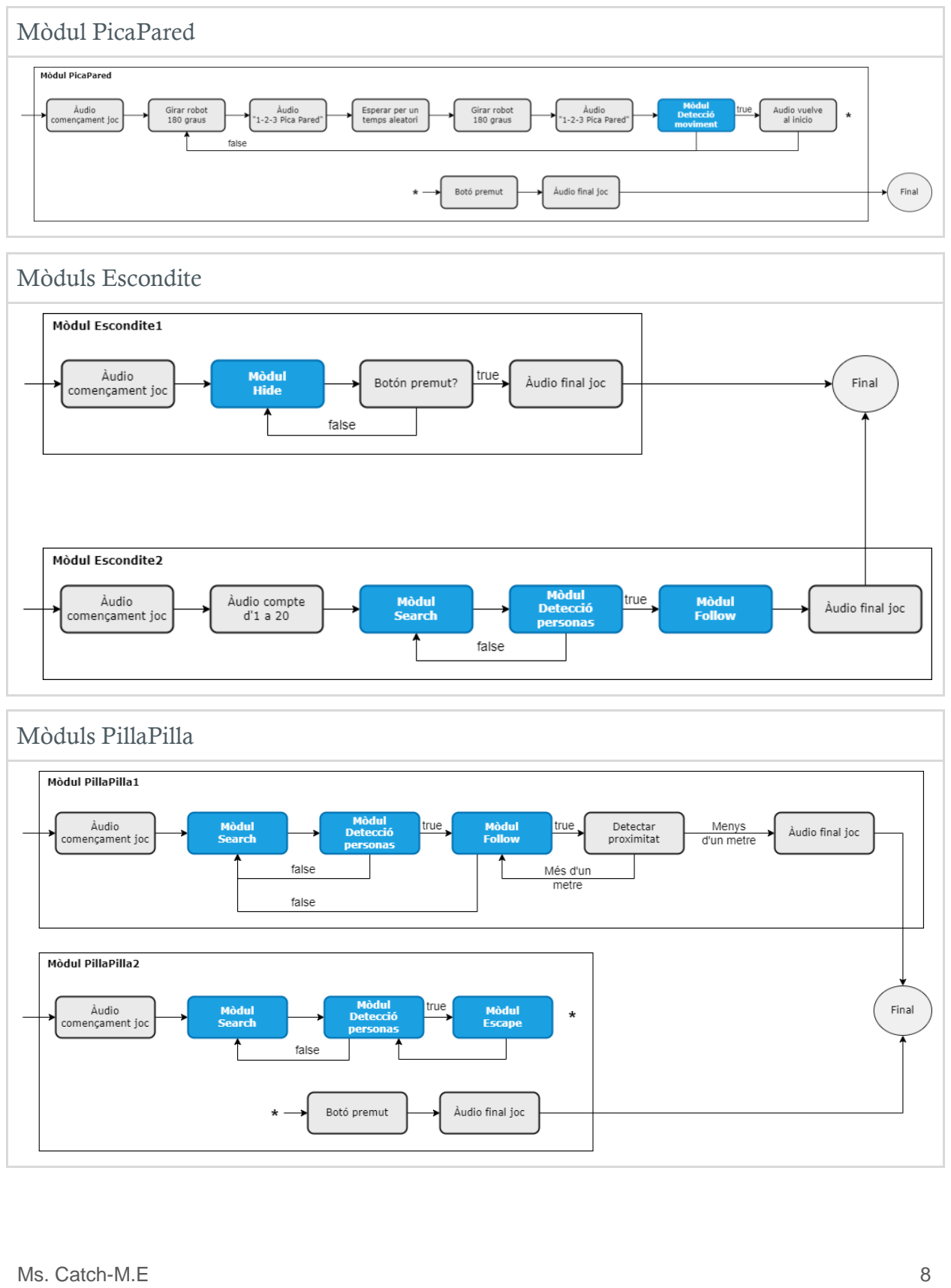
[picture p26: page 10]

Ms. Catch-M.E | 8

Mòdul PicaPared

Mòduls Escondite

Mòduls PillaPilla

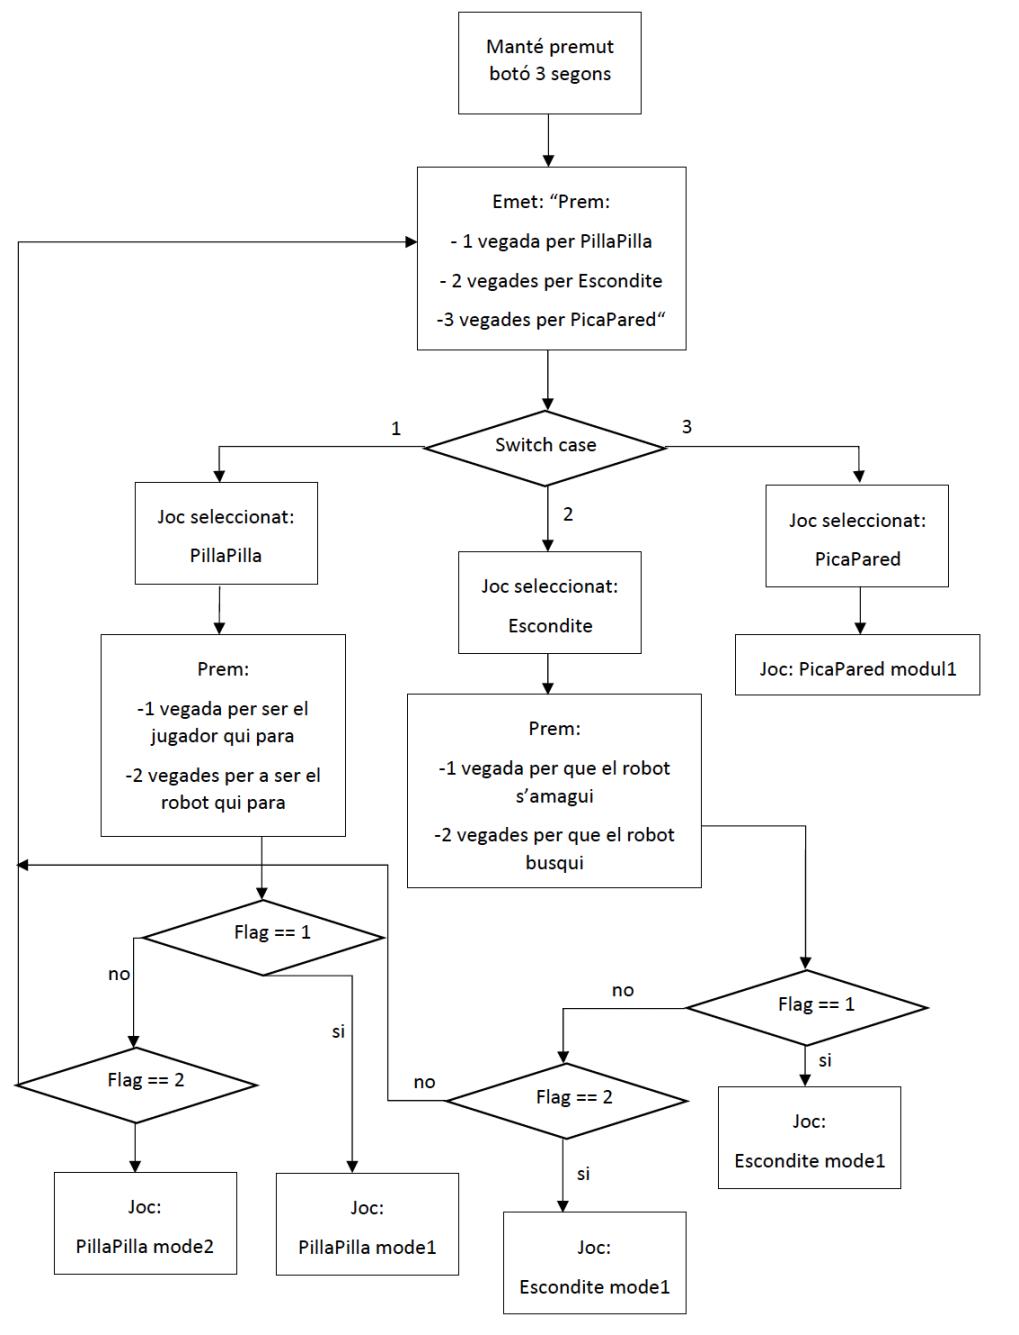
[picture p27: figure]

Ms. Catch-M.E | 9

Diagrames de flux

Selecció de Joc

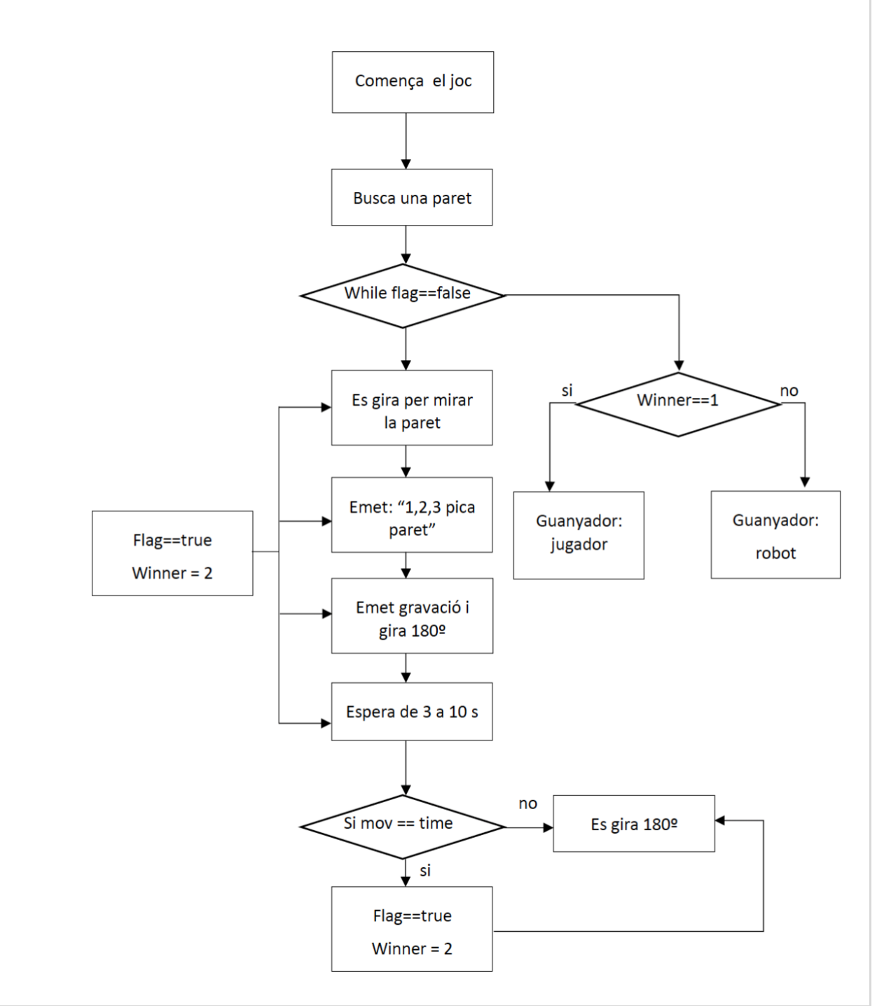
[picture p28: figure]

Ms. Catch-M.E | 10

PicaPared

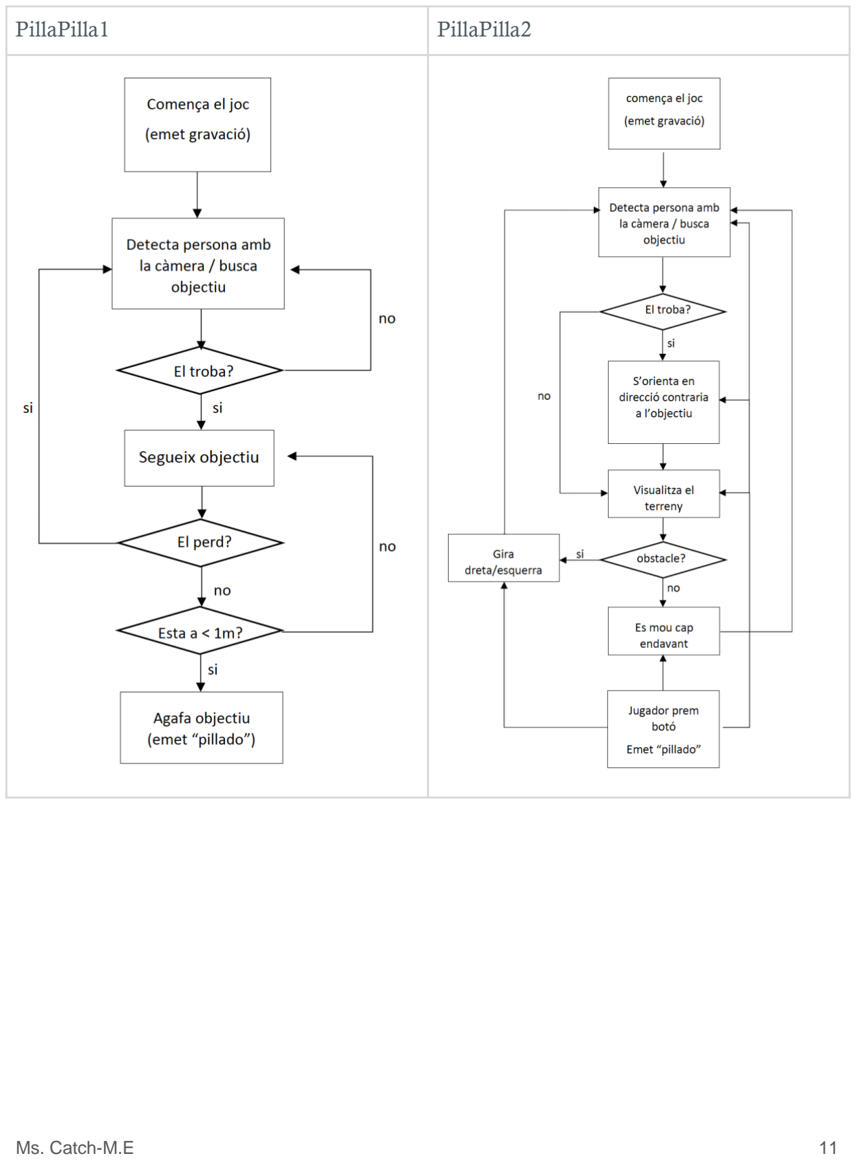
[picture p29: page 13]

Ms. Catch-M.E | 11
PillaPilla1 | PillaPilla2


Ms. Catch-M.E | 12

Escondite1


Ms. Catch-M.E | 13

Escondite2

Ms. Catch-M.E | 14

Contribucions Rellevants

El món de les joguines ha anat evolucionant amb la tecnologia per fer productes més interactius i divertits pels nens petits. Tot i això, cap dels productes és tan avançat com el projecte plantejat. La majoria de les joguines només tenen control per veu o funcionalitats simples per emetre so. En canvi, el robot resultant d’aquest projecte no s’assembla a res en el mercat, amb tantes funcions que tinguin tanta visió per computador. La raó principal d’aquesta diferència ve pel cost de producció i l’elevat preu comercial corresponent. Tot i això, un cop el projecte arribi a la fase de prototip es podria investigar com baixar els costos, especialment en construir el robot en massa. Així i tot, la complexitat que té aquest projecte no ha sigut comercialitzada a gran escala.

A més a més, les funcionalitats d’alguns dels mòduls independents ja plantejats es podrien extrapolar a altres camps. L’exemple més clar està al mòdul de detecció de persones. En el robot no es té pensat la implementació per aquest fi, però es podria fer servir per als camps de seguretat i vigilància en una casa o apartament. Si algun lladre entrés, el robot podria enviar una alerta a la policia. D’aquesta manera amb els mòduls que es volen implementar, es poden afegir fàcilment més funcionalitats a futur.

Aquest projecte està dissenyat per arribar a un 10 de nota en el cas que es compleixi tots els objectius principals. Durant el seu desenvolupament i implementació, amb aquest robot es treballarà la part hardware i la part software incloent la visió per computador. En aconseguir-ho, al final es tindrà un robot funcional capaç d’interactuar amb els participants en diversos jocs a través d’una càmera, una demo d’una joguina bastant completa.


Ms. Catch-M.E | 15

Components Extra i Peces 3D

En total, s’han imprès vuit conjunts de peces amb les impressores 3D. D’aquestes, només el suport per la càmera Raspberry i pels motors no són dissenys propis. A més a més, també s’han fet bases circulars de cartó per l’interior del cos del robot amb l’objectiu de col·locar tots els components electrònics.

Cap dividit | Cara amb ulls
Cos dividit | Suport per la roda


Ms. Catch-M.E | 16
Separador cargol M2 | Suports M3
Suport pels motors | Suport per la càmera Raspberry

Estrategia de Validació, Testing i Simulació

Per començar, s'hauria de fer testing de cada component individualment i a més en conjunt per comprovar que accepti les entrades i generi les sortides esperades. D'aquesta manera, es facilitarà la detecció de quina part del codi és la que no funciona. La idea és separar totes les funcionalitats en mòduls diferents, com ja s’ha fet a l’arquitectura del software, per poder desglossar les seves execucions tant per fer la validació com per fer el test d'aquests. Després, s’aniran ajuntant els diferents mòduls i es realitzaran els tests corresponents per aquests. En el grup s’ha tractat de seguir la metodologia de TDD, aprofitant que tenim un integrant de la menció d'enginyeria del software, per tractar de fer la validació i el testing a la vegada.

Ms. Catch-M.E | 17

Riscos Detectats i Plans de Contingencia

Durant el desenvolupament de qualsevol projecte, s’ha de tenir en compte els possibles riscos a assolir i quines mesures s’haurien de tomar. Aquests són els riscos principals del projecte:

Risk # | Description | Probability | Impact | Contingency plan
R01 | Poca velocitat als motors | High | Medium | Intentar obtenir motors amb més potencia o velocitat, depenent del problema. També es podria utilitzar una sèrie d’engranatges per adequar la força i la velocitat al nostre robot. A més a més, s’hauria de comprovar si les piles tenen bateries.
R02 | La recepció wifi que rep la Raspberry no és suficient | Medium | Medium | Tenir en compte alternatives de targetes de xarxa USB amb millor recepció.
R03 | Necessitat de components addicionals | Medium | High | Tractar d'extrapolar el funcionament del component necessitat a un altre. Si no és possible, tractar d'obtenir-lo a un preu raonable.
R04 | No tenir les impressions 3D a temps | Low | High | Utilitzar una impressora 3D pròpia, Erik Becerra disposa d'una, o fer algunes peces a partir de cartó.
R05 | Tenir problemes amb la Raspberry Pi | Low | High | Canviar la Raspberry Pi per una altra que té un dels membres del grup


Ms. Catch-M.E | 18

## Referències

Aquest projecte ha estat inspirat pels següents projectes de internet:

https://www.youtube.com/watch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

Statues/GLRL Game | Tag Game

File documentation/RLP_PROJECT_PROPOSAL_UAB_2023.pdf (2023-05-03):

Ms. Catch-M.E.

AUTHORS

Adrian Vargas Orellana

Marina Bermúdez Granados

Laia Rubio Castro

Erik Becerra Moreno

Erik Villarreal Gallardo


## Arduino automated robot than plays games with you

ROBÒTICA, LLENGUATGE I PLANIFICACIÓ – ENGINYERIA INFORMÀTICA - UAB

# Catch Player

Component | Units | Price/Unit | Budget
Adafruit Motor Shield para Arduino v2.3 | 1 | 24,75 | 24,75
Motor con eje ángulo recto y reductora 48:1 | 2 | 2,5 | 5
Altavoz con caja - 3W | 1 | 4,35 | 4,35
Sensor de distancia por ultrasonidos HC-SR04 | 2 | 1,80 | 3,60
Pulsador arcade con interruptor (Rojo) | 1 | 3,75 | 3,75
Raspberry pi 3 model B+ | 1 | 32,18 | 32,18
AVR ARDUINO UNO REV 3 | 1 | 22,45 | 22,45
Bateria Recargable 8.4 V | 2 | 7,84 | 15,68
Arducam 5MP 1080p OV5647 RASPBERRY PI | 1 | 17,09 | 17,09
ADAPTADOR 9V A JACK ALIMENTACIÓN 5.5X2.1MM POSITIVO INTERIOR | 2 | 0,31 | 0,62
TOTAL : | | | 129,47


# Relevant links:


https://www.youtube.com/watch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

# Internet project in which my robot is inspired

Statues/GLRL Game | Tag Game

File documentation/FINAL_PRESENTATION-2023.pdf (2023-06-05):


Ms. Catch - M.E.

Adrian Vargas Orellana - 1606868
Marina Bermúdez Granados - 1599120 Laia Rubio Castro - 1600830
Erik Becerra Moreno - 1529079
Erik Villarreal Gallardo - 1599119

## Arduino automated robot than plays games with you

ROBÒTICA, LLENGUATGE I PLANIFICACIÓ – ENGINYERIA INFORMÀTICA - UAB

# 1. Arquitectura HW i SW



# 2. Algorísmica

# Visió per Computador: Detecció de moviment

# Control HW: Control de la càmera Control de l’altaveu Control dels motors

# FOTOS, VIDEO i Git


https://youtu.be/ik0ufMCvqKk

https://github.com/Nara-On/MsCatch-ME

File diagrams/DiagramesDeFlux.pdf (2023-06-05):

Pilla pilla normal; Comença el joc; (emet gravació); Detecta persona amb la càmera / busca objectiu; Segueix objectiu; El troba?; Esta a < 1m?; Agafa objectiu (emet “pillado”); El perd?

Pilla pilla inverso

comença el joc; (emet gravació); Detecta persona amb la càmera / busca objectiu; S’orienta en direcció contraria a l’objectiu; obstacle?; Visualitza el terreny; Gira dreta/esquerra; Es mou cap endavant; El troba?; Jugador prem botó; Emet “pillado”

escondite

Comença el joc; (compta fins a 20); Detecta persona amb la càmera / busca objectiu; El troba?; Es dirigeix cap a l’objectiu; Canvia de posició; obstacle?; Gira dreta/esquerra; Es mou cap endavant; Visualitza el terreny; Esta a < 1m?; Agafa l’objectivo (emet “pillado”); El perd?

Escondite inverso

Comença el joc; (emet gravació); Visualitza el terreny; obstacle?; Es posiciona darrera d’aquest; Detecta persona amb la càmera / busca objectiu; El troba?; Es queda allà/ s’amaga; Prem el botó?; Guanya; (emet he guanyat); Perd; (emet has guanyat); Canvia de posició

PicaParet

Comença el joc; Busca una paret; While flag==false; Es gira per mirar la paret; Emet: “1,2,3 pica paret”; Emet gravació i gira 180º; Espera de 3 a 10 s; Si mov == time; Flag==true; Winner = 2; Es gira 180º; Guanyador: jugador; Guanyador:; robot; Winner==1
Manté premut botó 3 segons; Switch case; Joc seleccionat:; PicaPared; Escondite; PillaPilla; Prem:; s’amagui; busqui; Joc: PicaPared modul1; Flag == 1; Flag == 2; Joc:; PillaPilla mode2; PillaPilla mode1; Escondite mode1

Selecció de joc

Emet: “Prem:
- 1 vegada per PillaPilla
- 2 vegades per Escondite
-3 vegades per PicaPared“

Prem:
-1 vegada per ser el
jugador qui para
-2 vegades per a ser el
robot qui para

-1 vegada per que el robot

-2 vegades per que el robot

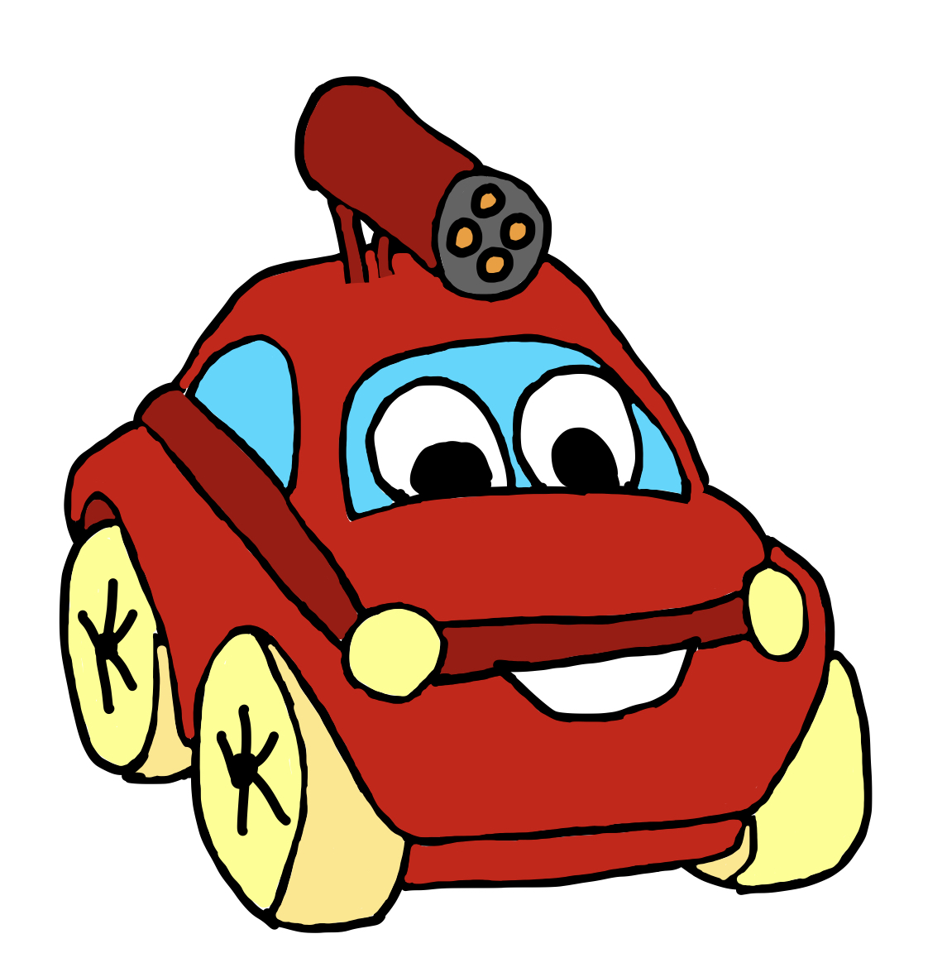
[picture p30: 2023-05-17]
documentation/images/initialDesignMsCatchME_1.jpeg

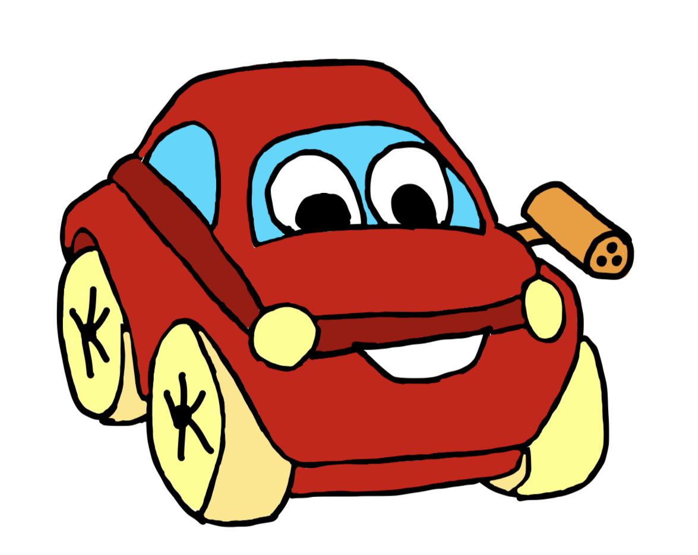
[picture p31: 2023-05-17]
documentation/images/initialDesignMsCatchME_2.jpeg

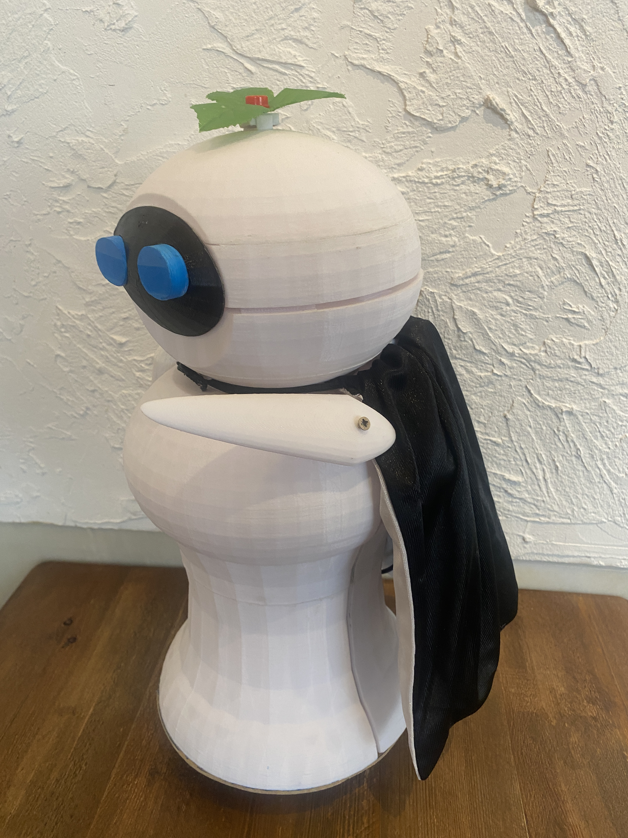
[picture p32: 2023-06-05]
documentation/images/photoMsCatchME_10.JPG

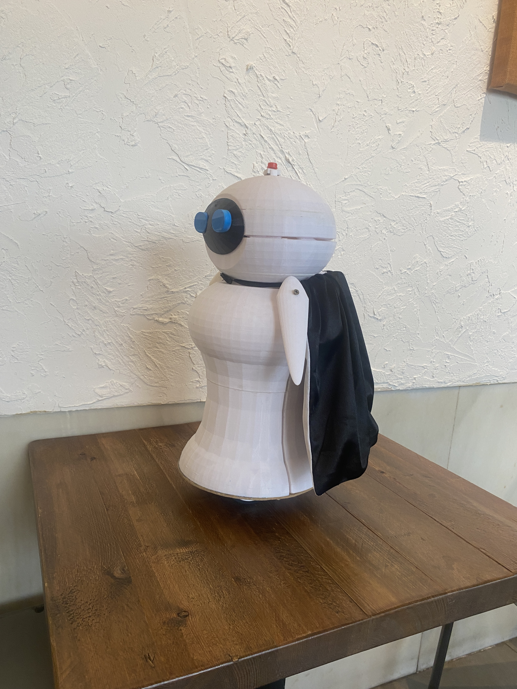
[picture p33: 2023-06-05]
documentation/images/photoMsCatchME_7.JPG

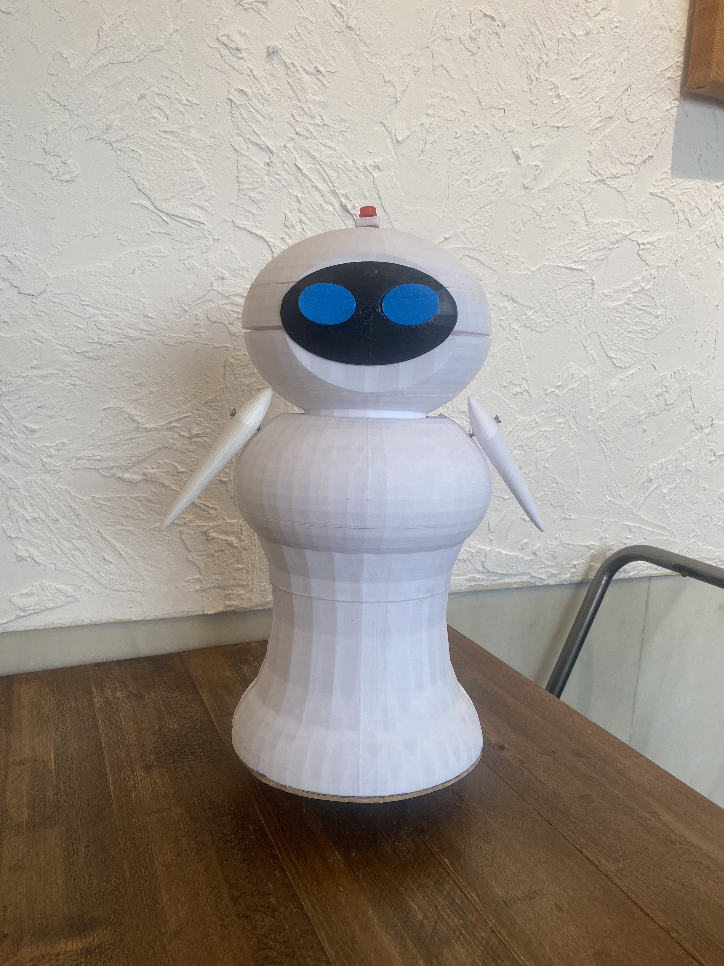
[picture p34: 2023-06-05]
documentation/images/photoMsCatchME_4.JPG

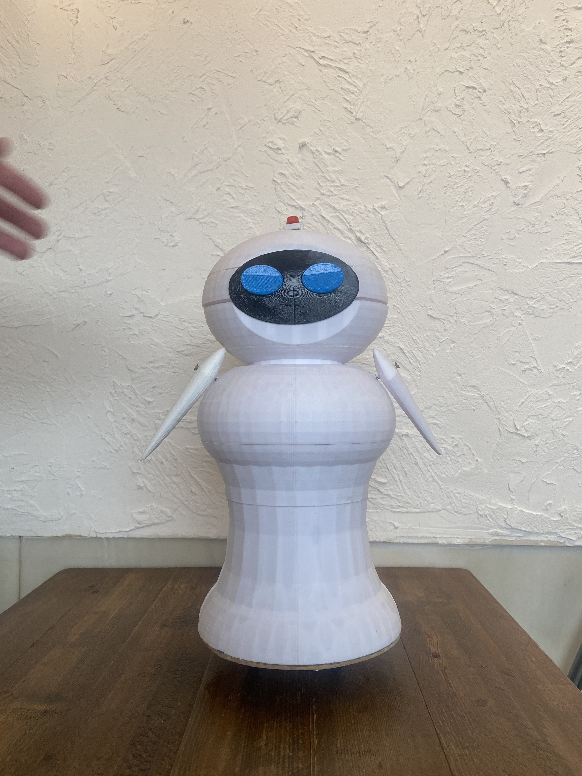
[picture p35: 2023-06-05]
documentation/images/photoMsCatchME_2.JPG

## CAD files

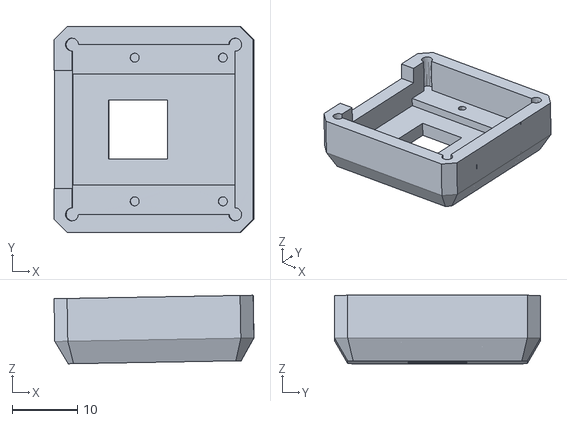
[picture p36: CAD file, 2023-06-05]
schematics/Raspberry CAM Holder.stl
30.6 x 31.5 x 10.5

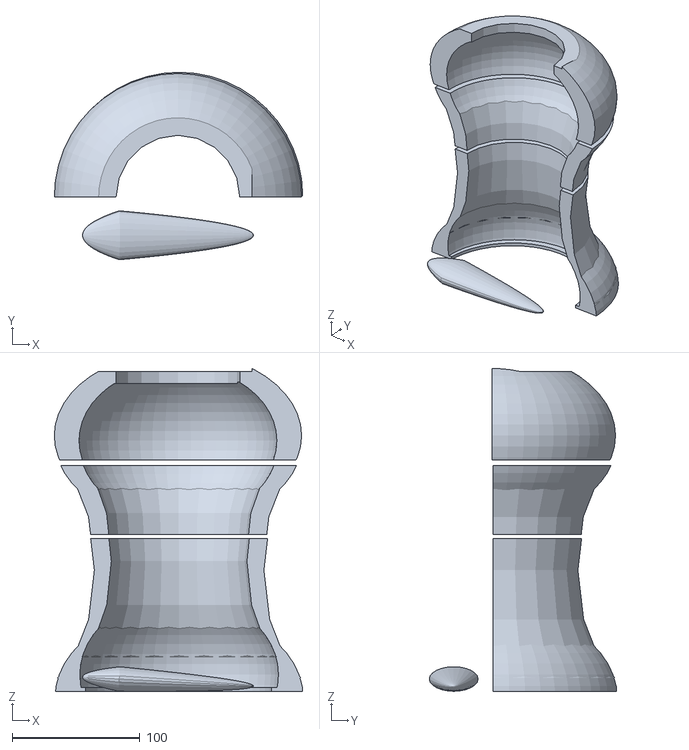
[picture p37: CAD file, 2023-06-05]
schematics/Divided Body.stl
194.5 x 146.7 x 252.8

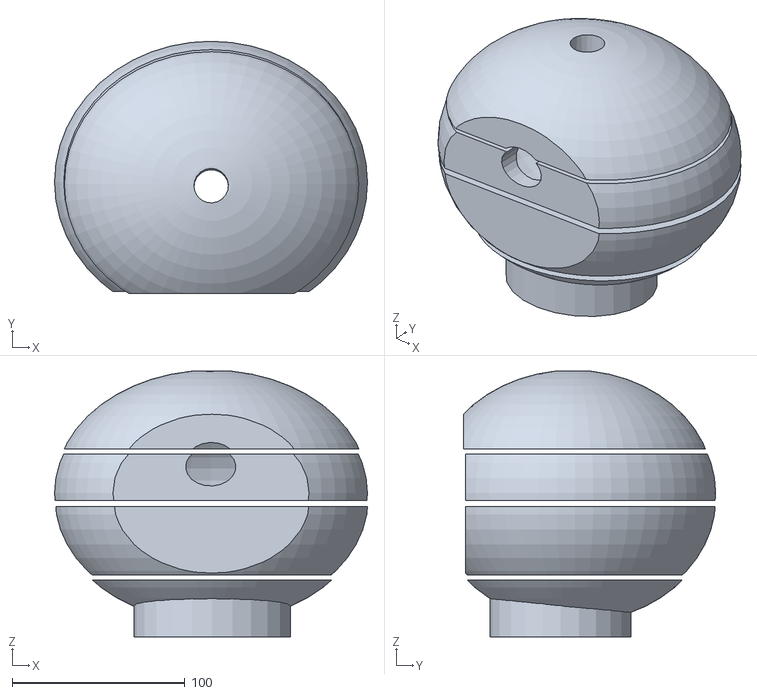
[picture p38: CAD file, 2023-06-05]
schematics/Divided Head.stl
181.3 x 146.2 x 154.0

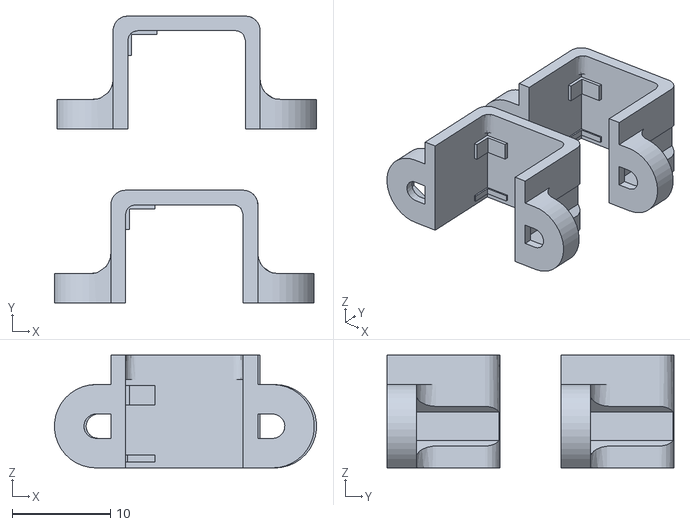
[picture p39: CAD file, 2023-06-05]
schematics/Motor Brackets.stl
26.7 x 29.2 x 11.5

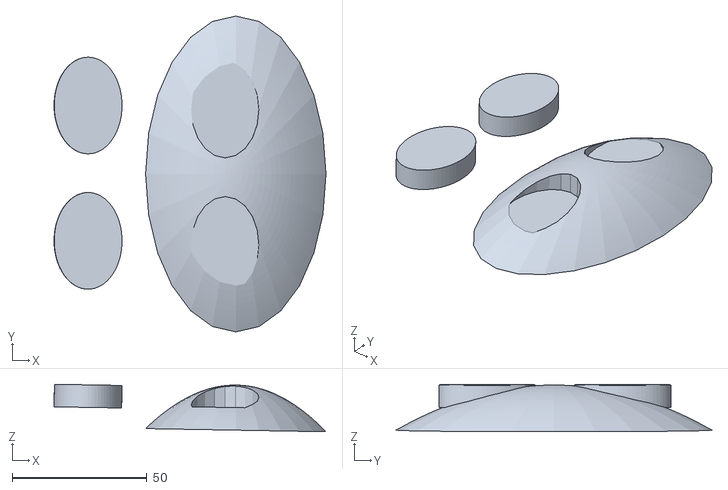
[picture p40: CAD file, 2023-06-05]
schematics/Face with Eyes.stl
101.0 x 117.2 x 17.6

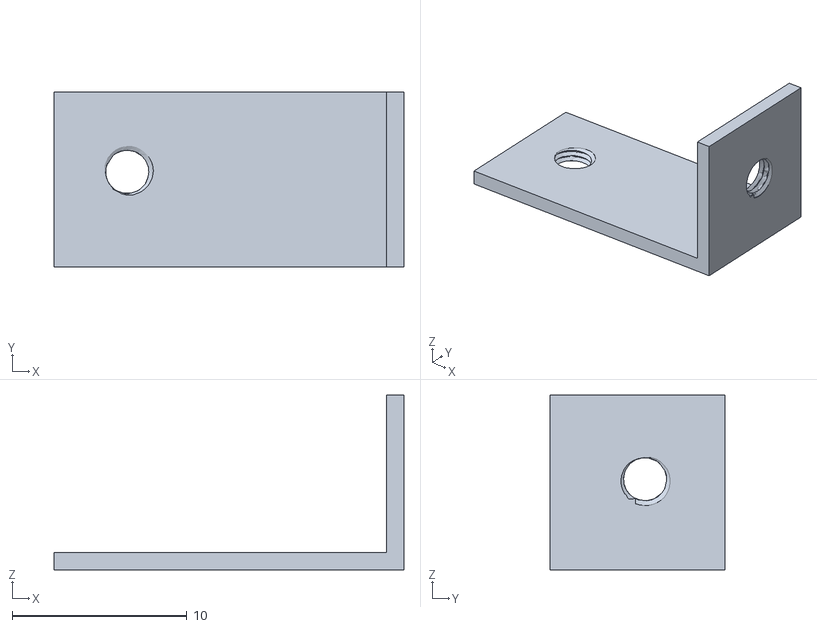
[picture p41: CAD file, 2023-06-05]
schematics/M3 Bracket.stl
20.0 x 10.0 x 10.0

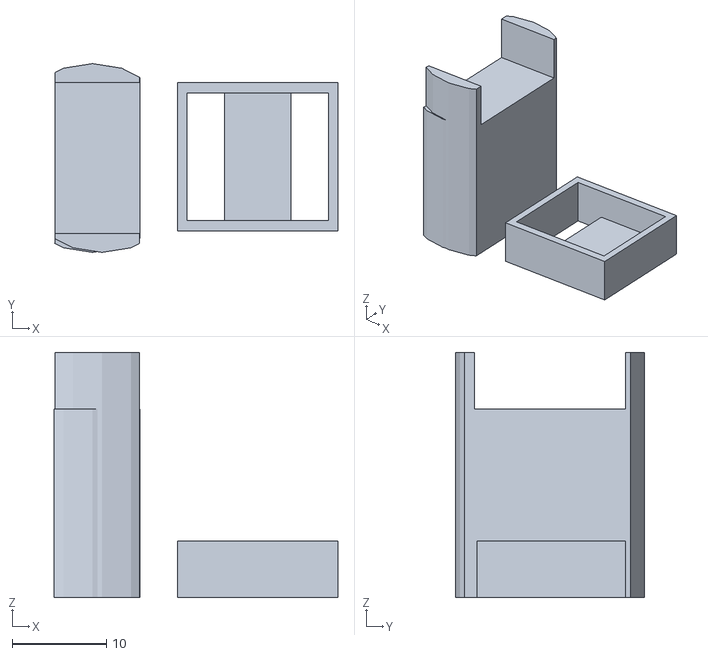
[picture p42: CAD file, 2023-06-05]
schematics/Button Support.stl
30.1 x 20.0 x 26.0

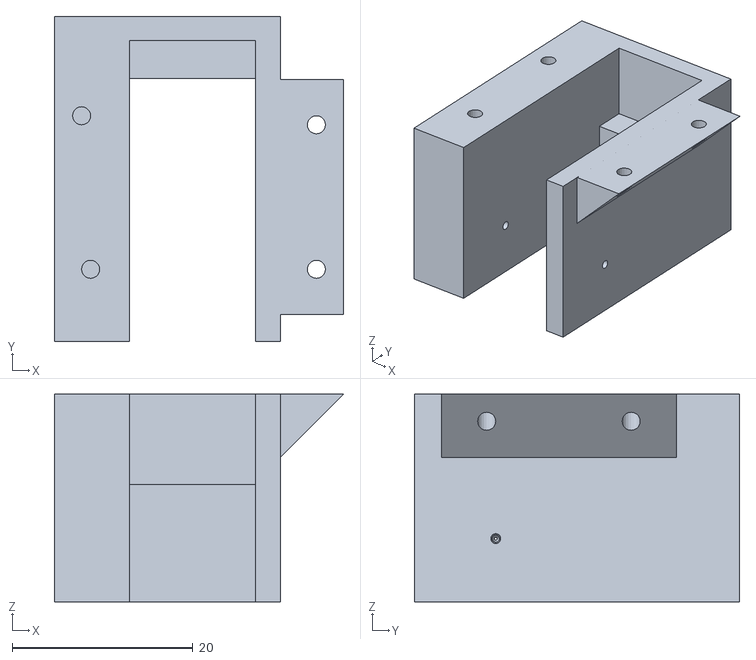
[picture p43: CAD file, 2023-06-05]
schematics/Wheel Support.stl
32.0 x 36.0 x 23.0

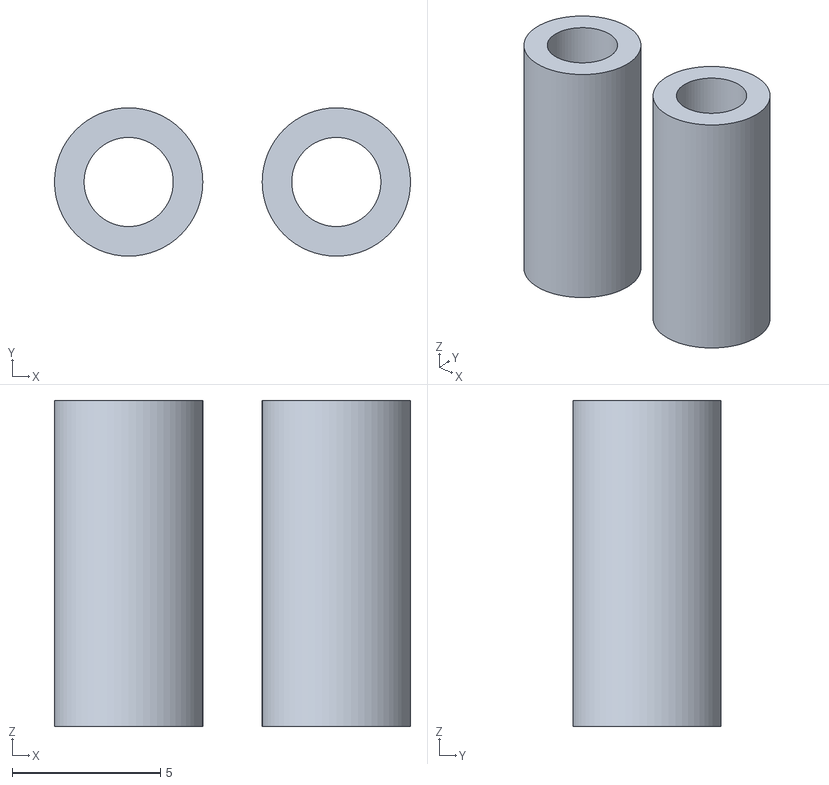
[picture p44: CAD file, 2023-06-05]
schematics/M2 screw spacers.stl
12.0 x 5.00 x 11.0

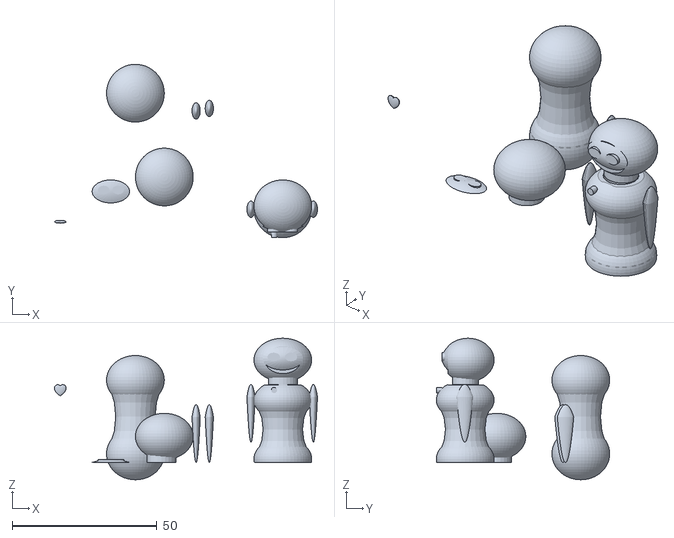
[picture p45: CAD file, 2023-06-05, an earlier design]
schematics/[UNUSED] EVA BETA.stl
91.0 x 60.0 x 49.0

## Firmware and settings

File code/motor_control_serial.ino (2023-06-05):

#include <AFMotor.h>

const unsigned int MAX_MESSAGE_LENGTH = 12; // saves 11 characters + end char '\0'

// communication
#include "catch_communication.h"
AF_DCMotor motor1 = AF_DCMotor(1, MOTOR12_1KHZ);
AF_DCMotor motor2 = AF_DCMotor(3, MOTOR34_1KHZ);


void message_to_command(char* message, int message_length) {
    if (message_length < 3) {
        Serial.println("NOT_ENOUGH_CHARACTERS");
        return;
    };

    AF_DCMotor* p_motor;
    switch (int(message[0])) {
        case catch_motor::SET_MOTOR_1:
            Serial.print("M1 ");
            p_motor = &motor1;
            break;
        case catch_motor::SET_MOTOR_2:
            Serial.print("M2 ");
            p_motor = &motor2;
            break;
    }

    switch (uint8_t(message[1])) {
        case FORWARD:
            p_motor->run(FORWARD);
            Serial.print("FORWARD ");
            break;
        case BACKWARD:
            p_motor->run(BACKWARD);
            Serial.print("BACKWARD ");
            break;
        case RELEASE:
            p_motor->run(RELEASE);
            Serial.print("STOP ");
            break;
    }

    Serial.print("SPEED ");
    p_motor->setSpeed(uint8_t(message[2]));
    Serial.print(uint8_t(message[2]));

    Serial.print("\n");
}


void setup() {
    Serial.begin(9600);
}


void loop() {
    static char message[MAX_MESSAGE_LENGTH];
    static unsigned int message_pos = 0;
    static bool too_many_chars = false;

    while (Serial.available() > 0) {
        char inByte = Serial.read(); // read the incoming byte:

        if ( inByte == '\n') { // message is over
            message[message_pos] = '\0';
            // Serial.println(message);
            if (!too_many_chars) {
                message_to_command(message, message_pos);
            } else {
                Serial.println("TOO_MANY_CHARS");
            }
            message_pos = 0;
            too_many_chars = false;
        }
        else if (message_pos >= MAX_MESSAGE_LENGTH - 1) {  // more characters sent than in buffer
            // message[message_pos] = '\0';
            // Serial.println(message);
            too_many_chars = true;
            message_pos = 0;
            message[message_pos] = inByte;
            message_pos++;
        }
        else {  // continue recording
            message[message_pos] = inByte;
            message_pos++;
        }
    }
}

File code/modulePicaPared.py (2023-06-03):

"""
Logica interna modulo Pica Pared

"""

#Librerias
import time
import random
import pygame
import RPi.GPIO as GPIO

from moduleDeteccion import *
from communication import *

pygame.mixer.init()
buttonPressed = False

def picaPared():

	# Preparar juego

	# Audio
	#soundInicio = pygame.mixer.Sound("/home/pi/Desktop/MsCatchME/code/audios/123ya.ogg")
	soundInicio = pygame.mixer.Sound('/home/pi/Desktop/MsCatchME/code/audios/PicaPared.wav')
	sound123picapared = pygame.mixer.Sound('/home/pi/Desktop/MsCatchME/code/audios/123picapared.ogg')
	sound123ya = pygame.mixer.Sound('/home/pi/Desktop/MsCatchME/code/audios/123ya.ogg')
	soundPillado = pygame.mixer.Sound('/home/pi/Desktop/MsCatchME/code/audios/PilladoHasPerdido.wav')
	soundWin = pygame.mixer.Sound('/home/pi/Desktop/MsCatchME/code/audios/MeHasPillado.wav')
	#soundLose = pygame.mixer.Sound('audios/PilladoHasPerdido.ogg')
	
	# Boton
	BUTTON_PIN = 15
	GPIO.setwarnings(False)
	GPIO.setmode(GPIO.BOARD)
	GPIO.setup(BUTTON_PIN, GPIO.IN, pull_up_down=GPIO.PUD_DOWN)
	
	global buttonPressed
	buttonPressed = False
	def buttonCallback(channel):
		global buttonPressed
		print("Button is pressed")
		buttonPressed = True
		
	GPIO.add_event_detect(BUTTON_PIN, GPIO.RISING, callback=buttonCallback)
	
	# Ruedas
	ard_com = ArduinoCommunication()
	time.sleep(2)
	
	comandoGiroM1 = CatchProtocol.command_to_binary(CatchProtocol.COMMAND.SET_MOTOR_1, CatchProtocol.DIRECTIONS.BACKWARD, 255)
	comandoGiroM2 = CatchProtocol.command_to_binary(CatchProtocol.COMMAND.SET_MOTOR_2, CatchProtocol.DIRECTIONS.FORWARD, 255)
	comandoStopM1 = CatchProtocol.command_to_binary(CatchProtocol.COMMAND.SET_MOTOR_1, CatchProtocol.DIRECTIONS.STOP, 0)
	comandoStopM2 = CatchProtocol.command_to_binary(CatchProtocol.COMMAND.SET_MOTOR_2, CatchProtocol.DIRECTIONS.STOP, 0)
	
	# Deteccion de personas
	th = 5

	
	# Audio comienzo juego
	playing = soundInicio.play()
	while playing.get_busy():
		pygame.time.delay(100)

	while not buttonPressed: #(boton no pulsado)
		#Girar 180
		ard_com.send_message(comandoGiroM1)
		ard_com.send_message(comandoGiroM2)
		time.sleep(2)
		if buttonPressed:
			break
		ard_com.send_message(comandoStopM1)
		ard_com.send_message(comandoStopM2)

		# Audio "123 picapared"
		playing = sound123picapared.play()
		while playing.get_busy():
			pygame.time.delay(100)
		if buttonPressed:
			break

		# Esperar entre 0 a 2 segundos
		#t = random.randrange(0, 2, 1)
		#print("Esperando " + str(t) + " segundos")
		time.sleep(1)
		if buttonPressed:
			break

		#Girar 180
		ard_com.send_message(comandoGiroM1)
		ard_com.send_message(comandoGiroM2)
		time.sleep(2)
		if buttonPressed:
			break
		ard_com.send_message(comandoStopM1)
		ard_com.send_message(comandoStopM2)

		# Audio "123 ya!"
		playing = sound123ya.play()
		while playing.get_busy():
			pygame.time.delay(100)
		if buttonPressed:
			break

		# Deteccion Movimiento
		mov = deteccionMov(th)
		
		if mov == True:
			# Audio "Te he pillado"
			playing = soundPillado.play()
			while playing.get_busy():
				pygame.time.delay(100)
			break

	
	if buttonPressed:
		playing = soundWin.play()
		while playing.get_busy():
			pygame.time.delay(100)
	"""
	else:
		playing = soundLose.play()
		while playing.get_busy():
			pygame.time.delay(100)
	"""
	GPIO.cleanup()

	return 0


if __name__ == '__main__':
	time.sleep(0.5)
	
	# Juego Pica Pared
	ret = picaPared()
	print(ret)

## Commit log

2023-05-03 3D design
    [Brazo.stl, Cabeza Base.stl, Cabeza Coronilla.stl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]
2023-06-02 Arduino code
2023-06-03 diagrames de flux
2023-06-03 Button fix
2023-06-04 Schematics updated
    [Brazo.stl, Button Support.stl, Cabeza Base.stl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]
2023-06-05 Cambios en el audio
